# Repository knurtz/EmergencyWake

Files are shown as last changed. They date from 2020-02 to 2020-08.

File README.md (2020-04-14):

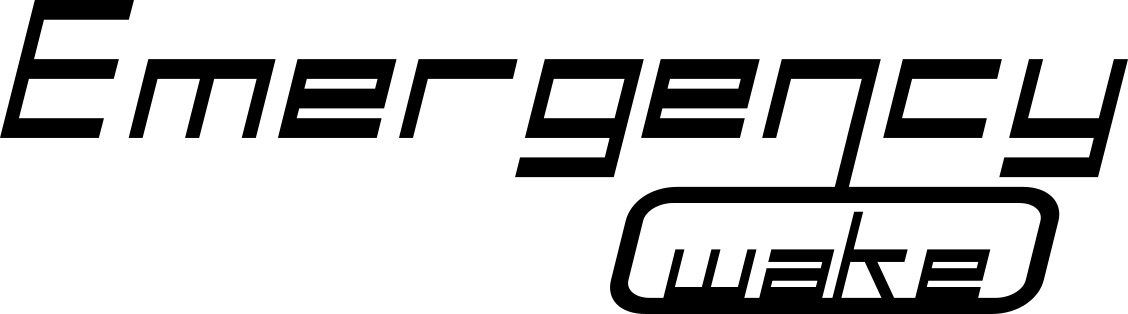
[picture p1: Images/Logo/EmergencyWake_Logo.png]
Emergency Wake


## Idea
A bedside alarm clock that uses a big red [emergency brake lever](https://www.google.com/search?tbm=isch&q=notbremse%20zug&tbs=imgo:1) as a snooze button.

To display the time, a vintage [VFD](https://en.wikipedia.org/wiki/Vacuum_fluorescent_display) is used.

An STM32 microcontroller and its RTC unit is used for tracking the time. It's in deep sleep most of the time.

Soundfiles from an SD card can be read by the microcontroller and played back through a small speaker.

Because of the VFD's relatively high power consumption, the clock can't run on battery power alone, so a USB-C connector is used for a 5 V power supply. 

In case of a power outage, a 3 V coin cell battery powers the microcontroller. In this scenario a small buzzer will be used instead of a wakeup melody, in order to use as little power as possible and to also notify the user, something's wrong. Also the display won't work.

Also, there will be support for a [DCF77](https://en.wikipedia.org/wiki/DCF77) radio clock module to automatically update the time.

A toggle switch allows programming two independent alarms. The times are set using a rotary encoder.

## Resources
- [Useful information](http://www.vwlowen.co.uk/arduino/vfd/vfd-clock.htm) about VFDs
- [A Guide to Fundamental VFD Operation](https://www.noritake-elec.com/technology/general-technical-information/vfd-operation)
- [Instructables page](https://www.instructables.com/id/A-Simple-Driver-for-VFD-Displays/) about controlling VFDs
- [Github project](https://github.com/AndruPol/ChibiOS-WavePlayer) about an STM32 wave player with ChibiOS
- [Github project](https://github.com/vanbwodonk/F4D_MP3) about an STM32 MP3 decoder
- [Another Github project](https://github.com/no111u3/stm32f4d_encoder/blob/master/main.c) about using the timer's encoder mode

## Components
- used emergency brake from eBay
- VFD from [pollin.de](https://www.pollin.de/p/vakuum-fluoreszenzdisplay-futaba-4-lt-46zb3-4-digit-121537) with additional parts:
  - [PT6312B](https://datasheet.lcsc.com/szlcsc/Princeton-Tech-PT6312B_C110225.pdf) VFD controller IC (requires negative voltages)
  - Alternative: UDN6118 VFD driver IC from eBay with no need for negative voltage
  - L9110 H-bridge for VFD filament
  - GL5516 light dependent resistor from eBay
- STM32F407VET6 microcontroller
- SD card holder from [Würth](https://www.we-online.de/katalog/datasheet/693071020811.pdf)
- DCF77 module from [pollin.de](https://www.pollin.de/p/dcf-empfangsmodul-dcf1-810054)
- CR2032 coin cell holder
- small buzzer
- toggle switch from [pollin.de](https://www.pollin.de/p/kippschalter-kn3-c-103a-1-polig-on-off-on-420023)
- rotary encoder from [reichelt.de](https://www.reichelt.de/drehimpulsegeber-15-impulse-30-rastungen-vertikal-stec11b03-p73913.html?r=1)
- MC34063 DCDC converter
- 5 V to 3.3 V step down regulator from [Würth](https://www.we-online.de/katalog/datasheet/173950378.pdf)
- [WM8960](https://datasheet.lcsc.com/szlcsc/Wolfson-Microelectronics-PLC-WM8960CGEFL-RV_C18752.pdf) audio codec with integrated class-D amplifier

## Usage
The clock will be in deep sleep most of the time. The display can be activated for about 10 seconds by tugging the emergency brake shortly.

While the time is being displayed, flipping the toggle switch into one of its two "on" positions allows setting the alarm times. In this mode, the alarms can each be (de-)activated by pulling the emergency lever once. A deactivated alarm will be represented by \_\_:\_\_ on the display.

Setting the alarm time is done by pressing the rotary encoder's push button to set the hours and then pressing it again to set the minutes. Alarm times are stored inside an EEPROM IC to avoid loss of settings after a power outage.

Once one alarm rings, pulling the emergency lever shortly will put it into snooze mode, pulling longer will deactivate the alarm.

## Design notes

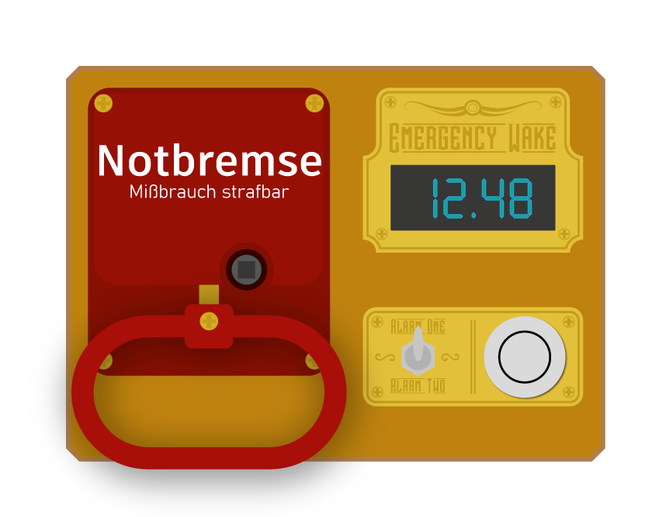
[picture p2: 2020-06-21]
BrassPlates/BrassPlateDisplay.png

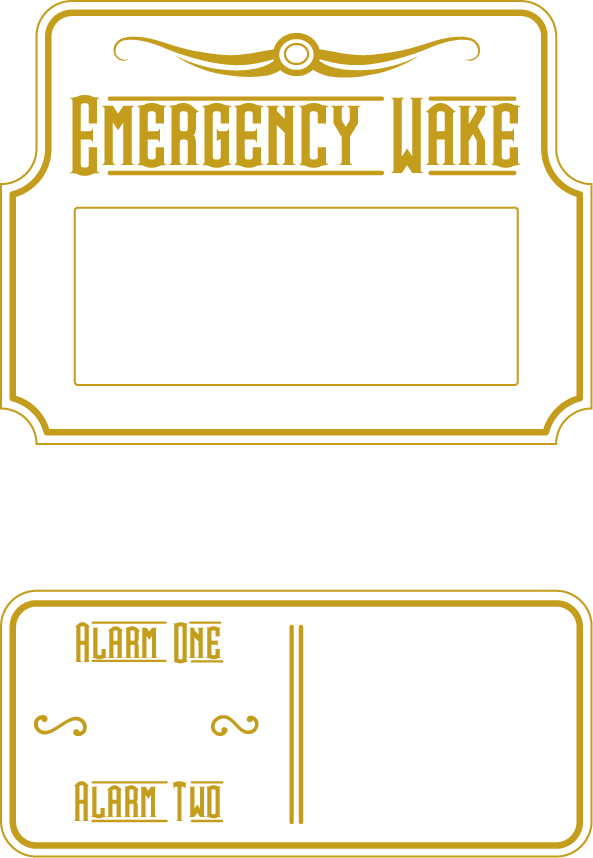
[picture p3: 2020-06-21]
BrassPlates/BrassPlateDisplay_PlaquesOnlyColor.png

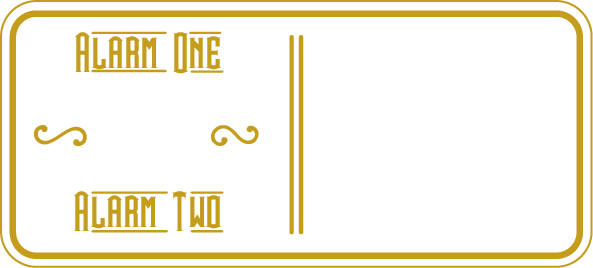
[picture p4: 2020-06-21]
BrassPlates/BrassPlateDisplay_LowerPlaqueOnly.png

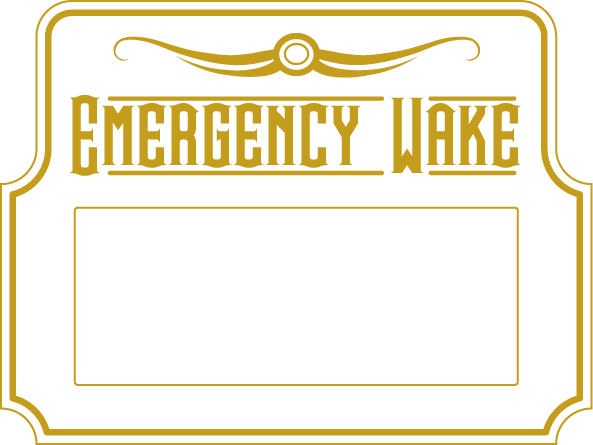
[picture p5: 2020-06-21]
BrassPlates/BrassPlateDisplay_UpperPlaqueOnly.png

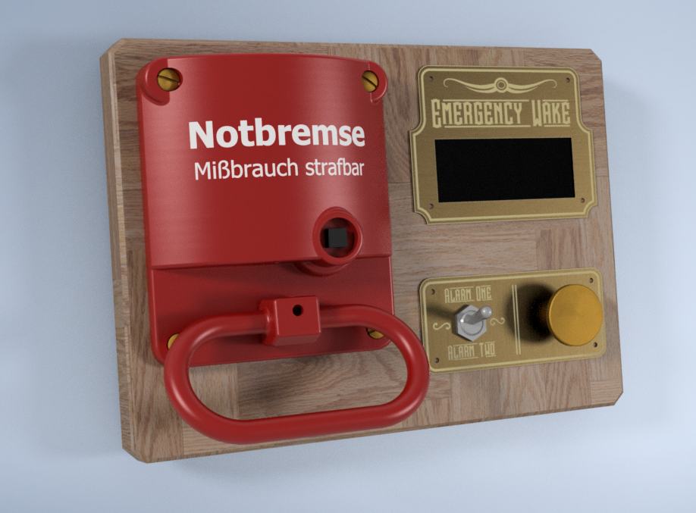
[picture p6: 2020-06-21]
CAD/Inventor/EmergencyWake.png

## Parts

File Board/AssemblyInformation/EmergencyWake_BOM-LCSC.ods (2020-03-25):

Designator | Comment | Footprint | LCSC Part #
C1 | 4u7,16V | Capacitor_SMD:C_0603_1608Metric | C19666
C8 C7 C6 C5 C4 C2 C23 C35 C15 C10 C39 C38 C37 | 100n | Capacitor_SMD:C_0402_1005Metric | C1525
C9 C26 C24 | 10u,25V | Capacitor_SMD:C_0805_2012Metric | C15850
C13 C36 | 22u,25V | Capacitor_SMD:C_0805_2012Metric | C45783
C16 | 470p | Capacitor_SMD:C_0603_1608Metric | C1620
C17 C12 C25 | 1u,50V | Capacitor_SMD:C_0603_1608Metric | C15849
C19 C20 | 30p | Capacitor_SMD:C_0402_1005Metric | C1570
C21 C22 | 15p | Capacitor_SMD:C_0402_1005Metric | C1548
C30 C31 C27 C29 C28 C32 C3 C11 | 10n,50V | Capacitor_SMD:C_0402_1005Metric | C15195
C34 C33 | 2.2u | Capacitor_SMD:C_0603_1608Metric | C23630
D2 D3 D4 D1 | white | LED_SMD:LED_0805_2012Metric_Castellated | C34499
D6 D5 | SS54 | Diode_SMD:D_SMA | C22452
Q1 Q3 | AO3400A | Package_TO_SOT_SMD:SOT-23 | C20917
Q2 Q4 Q5 | AO3401A | Package_TO_SOT_SMD:SOT-23 | C15127
R3 R2 R4 R5 | 150 | Resistor_SMD:R_0402_1005Metric | C25082
R9 R11 R31 R32 R33 R28 R29 R34 R8 R1 R10 R12 R13 R14 R16 R40 R15 R17 R47 R48 R30 R49 R50 R42 | 100k | Resistor_SMD:R_0402_1005Metric | C25741
R19 | 75k | Resistor_SMD:R_0603_1608Metric | C23242
R20 R6 R43 | 5.1k | Resistor_SMD:R_0603_1608Metric | C23186
R23 | 20k | Resistor_SMD:R_0603_1608Metric | C4184
R25 | 51k | Resistor_SMD:R_0603_1608Metric | C23196
R26 R27 R7 R44 R45 R46 | 10k | Resistor_SMD:R_0402_1005Metric | C25744
R35 R36 | 390 | Resistor_SMD:R_0603_1608Metric | C23151
R39 R38 R37 | 10k | Resistor_SMD:R_0603_1608Metric | C25804
U1 | M24C02-WMN | Package_SO:SOIC-8_3.9x4.9mm_P1.27mm | C7562
U2 | AMS1117-3.3 | Package_TO_SOT_SMD:SOT-223-3_TabPin2 | C6186
U3 | MC34063AD | Package_SO:SOIC-8_3.9x4.9mm_P1.27mm | C32078
U4 | STM32F407VETx | Package_QFP:LQFP-100_14x14mm_P0.5mm | C28730
U7 | PT6312B | Package_QFP:LQFP-44_10x10mm_P0.8mm | C110225
U9 U8 | EL357N-G | Package_SO:SOP-4_3.8x4.1mm_P2.54mm | C6649
U10 | L9110S | Package_SO:SOP-8_3.76x4.96mm_P1.27mm | C85174
U11 | SRV05-4 | Package_TO_SOT_SMD:SOT-23-6 | C85364
Y1 | 32768 | Crystal:Crystal_SMD_3215-2Pin_3.2x1.5mm | C32346
Y2 | 8M | Crystal:Crystal_SMD_5032-2Pin_5.0x3.2mm | C115962

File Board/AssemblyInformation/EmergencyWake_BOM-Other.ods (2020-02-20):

Reference | Quantity | Value | Footprint
BZ1 | 1 | Buzzer | Buzzer_Beeper:Buzzer_12x9.5RM7.6
DISP1 | 1 | FUTABA_4-LT-46ZB3 | VFD:FUTABA_4-LT-46ZB3
J3 | 1 | Conn_01x03 | Connector_PinHeader_2.54mm:PinHeader_1x03_P2.54mm_Horizontal
J5 | 1 | Conn_01x05 | Connector_PinHeader_2.54mm:PinHeader_1x05_P2.54mm_Horizontal
J7,J4 | 2 | Conn_01x02 | Connector_PinHeader_2.54mm:PinHeader_1x02_P2.54mm_Horizontal
J8,J10 | 2 | Conn_01x04 | WR-WTB:WR-WTB 2.00mm SMT Male Horizontal Shrouded Header 4 Pins
J9,J6 | 2 | Conn_01x04 | Connector_PinHeader_2.54mm:PinHeader_1x04_P2.54mm_Horizontal
JP4,JP1,JP2,JP3 | 4 | SolderJumper_3_Open | Jumper:SolderJumper-3_P1.3mm_Open_RoundedPad1.0x1.5mm_NumberLabels
JP5,JP6 | 2 | SolderJumper_2_Open | Jumper:SolderJumper-2_P1.3mm_Open_TrianglePad1.0x1.5mm
NT1 | 1 | Net-Tie_2 | NetTie:NetTie-2_SMD_Pad2.0mm
R24 | 1 | GL5516 | OptoDevice:R_LDR_5.1x4.3mm_P3.4mm_Vertical
TP1 | 1 | 5V in | TestPoint:TestPoint_Loop_D1.80mm_Drill1.0mm_Beaded
TP10 | 1 | Vdrive | TestPoint:TestPoint_Loop_D1.80mm_Drill1.0mm_Beaded
TP11 | 1 | DCF | TestPoint:TestPoint_Loop_D1.80mm_Drill1.0mm_Beaded
TP2 | 1 | GND in | TestPoint:TestPoint_Loop_D1.80mm_Drill1.0mm_Beaded
TP3 | 1 | 5V | TestPoint:TestPoint_Loop_D1.80mm_Drill1.0mm_Beaded
TP4 | 1 | VCC | TestPoint:TestPoint_Loop_D1.80mm_Drill1.0mm_Beaded
TP5 | 1 | DCDC in | TestPoint:TestPoint_Loop_D1.80mm_Drill1.0mm_Beaded
TP6 | 1 | GND | TestPoint:TestPoint_Loop_D1.80mm_Drill1.0mm_Beaded
TP7 | 1 | Audio | TestPoint:TestPoint_Loop_D1.80mm_Drill1.0mm_Beaded
TP8 | 1 | -VDC | TestPoint:TestPoint_Loop_D1.80mm_Drill1.0mm_Beaded
TP9 | 1 | LDR | TestPoint:TestPoint_Loop_D1.80mm_Drill1.0mm_Beaded

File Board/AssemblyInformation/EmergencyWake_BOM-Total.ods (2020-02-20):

Reference | Quantity | Value | Footprint | Würth | LCSC
C8,C7,C6,C5,C4,C2,C23,C35,C15,C10 | 10 | 100n | Capacitor_SMD:C_0402_1005Metric |  | C1525
C16 | 1 | 470p | Capacitor_SMD:C_0603_1608Metric |  | C1620
R23 | 1 | 20k | Resistor_SMD:R_0603_1608Metric |  | C4184
U2 | 1 | AMS1117-3.3 | Package_TO_SOT_SMD:SOT-223-3_TabPin2 |  | C6186
U9,U8 | 2 | EL357N-G | Package_SO:SOP-4_3.8x4.1mm_P2.54mm |  | C6649
U1 | 1 | M24C02-WMN | Package_SO:SOIC-8_3.9x4.9mm_P1.27mm |  | C7562
C9 | 1 | 10u,50V | Capacitor_SMD:C_1206_3216Metric |  | C13585
Q2 | 1 | AO3401A | Package_TO_SOT_SMD:SOT-23 |  | C15127
C30,C31,C27,C29,C28,C32,C3,C11 | 8 | 10n,50V | Capacitor_SMD:C_0402_1005Metric |  | C15195
C17,C12,C25,C24 | 4 | 1u,50V | Capacitor_SMD:C_0603_1608Metric |  | C15849
C26 | 1 | 10u,50V | Capacitor_SMD:C_0805_2012Metric |  | C15850
C1 | 1 | 4u7,16V | Capacitor_SMD:C_0603_1608Metric |  | C19666
Q1,Q3 | 2 | AO3400A | Package_TO_SOT_SMD:SOT-23 |  | C20917
D6,D5 | 2 | SS54 | Diode_SMD:D_SMA |  | C22452
R22,R21 | 2 | 300k | Resistor_SMD:R_0603_1608Metric |  | C23024
R35,R36 | 2 | 390 | Resistor_SMD:R_0603_1608Metric |  | C23151
R20,R6,R43 | 3 | 5.1k | Resistor_SMD:R_0603_1608Metric |  | C23186
R25 | 1 | 51k | Resistor_SMD:R_0603_1608Metric |  | C23196
R19 | 1 | 75k | Resistor_SMD:R_0603_1608Metric |  | C23242
C34,C33 | 2 | 2.2u | Capacitor_SMD:C_0603_1608Metric |  | C23630
R3,R2,R4,R5 | 4 | 150 | Resistor_SMD:R_0402_1005Metric |  | C25082
R9,R11,R31,R32,R33,R28,R30,R29,R34,R8,R1,R10,R12,R13,R14,R16,R40,R15,R17,R41,R42,R47,R48 | 23 | 100k | Resistor_SMD:R_0402_1005Metric |  | C25741
R26,R27,R7,R44,R45,R46 | 6 | 10k | Resistor_SMD:R_0402_1005Metric |  | C25744
R39,R38,R37 | 3 | 10k | Resistor_SMD:R_0603_1608Metric |  | C25804
U4 | 1 | STM32F407VETx | Package_QFP:LQFP-100_14x14mm_P0.5mm |  | C28730
U3 | 1 | MC34063AD | Package_SO:SOIC-8_3.9x4.9mm_P1.27mm |  | C32078
D2,D3,D4,D1 | 4 | white | LED_SMD:LED_0805_2012Metric_Castellated |  | C34499
C21,C22 | 2 | 6p | Capacitor_SMD:C_0402_1005Metric |  | C37474
C13 | 1 | 22u,25V | Capacitor_SMD:C_0805_2012Metric |  | C45783
C19,C20 | 2 | 10n | Capacitor_SMD:C_0603_1608Metric |  | C57112
U10 | 1 | L9110S | Package_SO:SOP-8_3.76x4.96mm_P1.27mm |  | C85174
U11 | 1 | SRV05-4 | Package_TO_SOT_SMD:SOT-23-6 |  | C85364
Y1 | 1 | 32768 | Crystal:Crystal_SMD_3215-2Pin_3.2x1.5mm |  | C94673
U7, | 1 | PT6312B | Package_QFP:LQFP-44_10x10mm_P0.8mm |  | C110225
U5 | 1 | LM4670 | Package_SON:WSON-8-1EP_3x3mm_P0.5mm_EP1.6x2.0mm |  | C131968
BT1 | 1 | Battery_Cell | Wuerth:79523141 | 79523141
U6 | 1 | 173950378 | Converter_DCDC:Converter_DCDC_RECOM_R-78B-2.0_THT | 173950378
L1 | 1 | 33u | Inductor_SMD:L_Wuerth_WE-PD-Typ-7345 | 7447773330
SW4,SW3,SW2 | 3 | SW_Push | Wuerth:436351045816 | 436351045816
SW1 | 1 | SW_DPDT_x2 | Wuerth:452404020202 | 452404020202
R18 | 1 | 0.18 | Wuerth:561070332057 | 561070332057
J1 | 1 | USB_C_Receptacle_USB2.0 | Wuerth:632723300011 | 632723300011
J2 | 1 | Micro_SD_Card_Det | Wuerth:693071020811 | 693071020811
C14 | 1 | 100u,50V | Capacitor_THT:CP_Radial_D6.3mm_P2.50mm | 860010573007
C18 | 1 | 33u,63V | Capacitor_THT:CP_Radial_D6.3mm_P2.50mm | 860010773011
BZ1 | 1 | Buzzer | Buzzer_Beeper:Buzzer_12x9.5RM7.6
DISP1 | 1 | FUTABA_4-LT-46ZB3 | VFD:FUTABA_4-LT-46ZB3
J3 | 1 | Conn_01x03 | Connector_PinHeader_2.54mm:PinHeader_1x03_P2.54mm_Horizontal
J5 | 1 | Conn_01x05 | Connector_PinHeader_2.54mm:PinHeader_1x05_P2.54mm_Horizontal
J7,J4 | 2 | Conn_01x02 | Connector_PinHeader_2.54mm:PinHeader_1x02_P2.54mm_Horizontal
J8,J10 | 2 | Conn_01x04 | WR-WTB:WR-WTB 2.00mm SMT Male Horizontal Shrouded Header 4 Pins
J9,J6 | 2 | Conn_01x04 | Connector_PinHeader_2.54mm:PinHeader_1x04_P2.54mm_Horizontal
JP4,JP1,JP2,JP3 | 4 | SolderJumper_3_Open | Jumper:SolderJumper-3_P1.3mm_Open_RoundedPad1.0x1.5mm_NumberLabels
JP5,JP6 | 2 | SolderJumper_2_Open | Jumper:SolderJumper-2_P1.3mm_Open_TrianglePad1.0x1.5mm
NT1 | 1 | Net-Tie_2 | NetTie:NetTie-2_SMD_Pad2.0mm
R24 | 1 | GL5516 | OptoDevice:R_LDR_5.1x4.3mm_P3.4mm_Vertical
TP1 | 1 | 5V in | TestPoint:TestPoint_Loop_D1.80mm_Drill1.0mm_Beaded
TP10 | 1 | Vdrive | TestPoint:TestPoint_Loop_D1.80mm_Drill1.0mm_Beaded
TP11 | 1 | DCF | TestPoint:TestPoint_Loop_D1.80mm_Drill1.0mm_Beaded
TP2 | 1 | GND in | TestPoint:TestPoint_Loop_D1.80mm_Drill1.0mm_Beaded
TP3 | 1 | 5V | TestPoint:TestPoint_Loop_D1.80mm_Drill1.0mm_Beaded
TP4 | 1 | VCC | TestPoint:TestPoint_Loop_D1.80mm_Drill1.0mm_Beaded
TP5 | 1 | DCDC in | TestPoint:TestPoint_Loop_D1.80mm_Drill1.0mm_Beaded
TP6 | 1 | GND | TestPoint:TestPoint_Loop_D1.80mm_Drill1.0mm_Beaded
TP7 | 1 | Audio | TestPoint:TestPoint_Loop_D1.80mm_Drill1.0mm_Beaded
TP8 | 1 | -VDC | TestPoint:TestPoint_Loop_D1.80mm_Drill1.0mm_Beaded
TP9 | 1 | LDR | TestPoint:TestPoint_Loop_D1.80mm_Drill1.0mm_Beaded

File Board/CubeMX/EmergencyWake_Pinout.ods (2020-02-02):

Position | Name | Type | Signal | Label
94 | BOOT0 | Boot
73 | NC | NC
14 | NRST | Reset
12 | OSC_IN | I/O
13 | OSC_OUT | I/O
23 | PA0-WKUP | I/O | SYS_WKUP
24 | PA1 | I/O | GPIO_EXTI1 | Lever
25 | PA2 | I/O
26 | PA3 | Output | GPIO_Output | Audio EN
29 | PA4 | I/O | DAC_OUT1 | Audio out
30 | PA5 | I/O
31 | PA6 | I/O | ADC1_IN6 | LDR in
32 | PA7 | I/O
67 | PA8 | I/O
68 | PA9 | I/O | USART1_TX
69 | PA10 | I/O | USART1_RX
70 | PA11 | I/O | USB_DM
71 | PA12 | I/O | USB_DP
72 | PA13 | I/O | SYS_JTMS-SWDIO
76 | PA14 | I/O | SYS_JTCK-SWCLK
77 | PA15 | I/O | SPI1_NSS
35 | PB0 | I/O
36 | PB1 | Output | GPIO_Output | Buzzer
37 | PB2 | I/O
89 | PB3 | I/O | SPI1_SCK
90 | PB4 | I/O | SPI1_MISO
91 | PB5 | I/O | SPI1_MOSI
92 | PB6 | I/O | I2C1_SCL
93 | PB7 | I/O | I2C1_SDA
95 | PB8 | I/O
96 | PB9 | I/O
47 | PB10 | I/O
48 | PB11 | I/O
51 | PB12 | Output | GPIO_Output | SPI2_STB
52 | PB13 | I/O | SPI2_SCK
53 | PB14 | I/O | SPI2_MISO
54 | PB15 | I/O | SPI2_MOSI
15 | PC0 | Output | GPIO_Output | LED1
16 | PC1 | Output | GPIO_Output | LED2
17 | PC2 | Output | GPIO_Output | LED3
18 | PC3 | Output | GPIO_Output | LED4
33 | PC4 | I/O
34 | PC5 | I/O
63 | PC6 | I/O | TIM8_CH1
64 | PC7 | I/O | TIM8_CH2
65 | PC8 | I/O | SDIO_D0
66 | PC9 | I/O
78 | PC10 | I/O
79 | PC11 | I/O
80 | PC12 | I/O | SDIO_CK
7 | PC13-TAMPER-RTC | I/O
8 | PC14-OSC32_IN | I/O | RCC_OSC32_IN
9 | PC15-OSC32_OUT | I/O | RCC_OSC32_OUT
81 | PD0 | I/O
82 | PD1 | I/O
83 | PD2 | I/O | SDIO_CMD
84 | PD3 | I/O
85 | PD4 | I/O
86 | PD5 | Output | GPIO_Output | SD enable
87 | PD6 | Input | GPIO_Input | SD detect
88 | PD7 | I/O
55 | PD8 | I/O
56 | PD9 | I/O
57 | PD10 | I/O
58 | PD11 | I/O
59 | PD12 | I/O | TIM4_CH1
60 | PD13 | I/O | TIM4_CH2
61 | PD14 | I/O
62 | PD15 | Output | GPIO_Output | DCDC enable
97 | PE0 | Output | GPIO_Output | EEPROM_NWC
98 | PE1 | I/O
1 | PE2 | I/O | GPIO_EXTI2 | EncoderButton
2 | PE3 | I/O | GPIO_EXTI3 | ToggleUp
3 | PE4 | I/O | GPIO_EXTI4 | ToggleDown
4 | PE5 | I/O | GPIO_EXTI5 | USR_BUT
5 | PE6 | I/O
38 | PE7 | I/O
39 | PE8 | I/O
40 | PE9 | I/O | TIM1_CH1 | DCF77 signal
41 | PE10 | Output | GPIO_Output | DCF77 enable
42 | PE11 | I/O
43 | PE12 | I/O
44 | PE13 | I/O
45 | PE14 | I/O
46 | PE15 | Input | GPIO_Input | VBUS sense
6 | VBAT | Power
11 | VDD | Power
28 | VDD | Power
50 | VDD | Power
75 | VDD | Power
100 | VDD | Power
22 | VDDA | Power
20 | VREF- | Power
21 | VREF+ | Power
10 | VSS | Power
27 | VSS | Power
49 | VSS | Power
74 | VSS | Power
99 | VSS | Power
19 | VSSA | Power

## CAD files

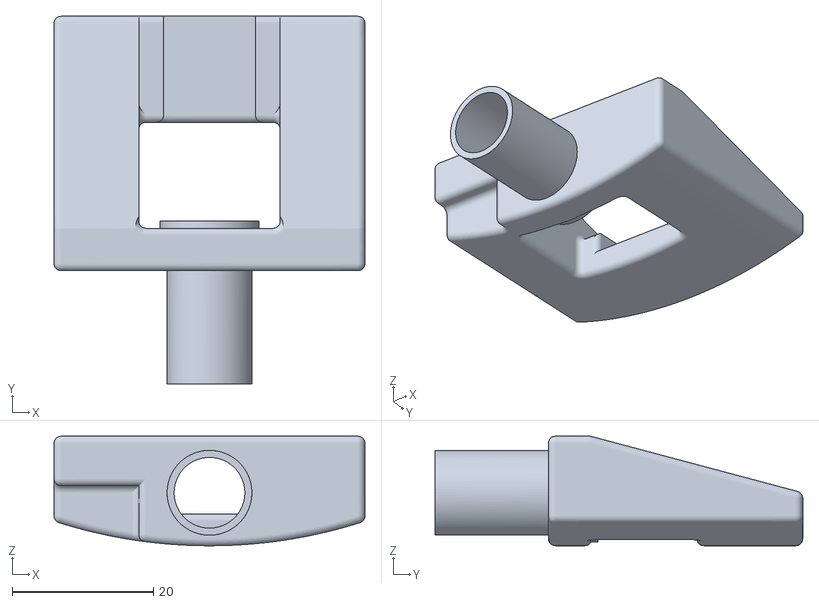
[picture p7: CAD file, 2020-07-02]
CAD/Inventor/STL/EW_KunststoffEinsatz.stl
44.0 x 52.0 x 15.5

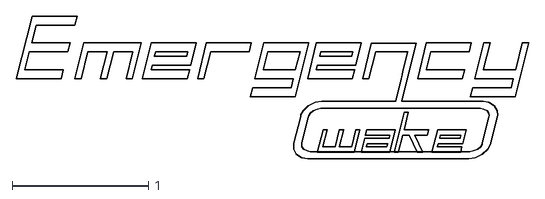
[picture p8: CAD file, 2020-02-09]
Images/Logo/EmergencyWake_Logo.dxf
3.76 x 1.05

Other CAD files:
CAD/Inventor/Board/436351045816_Download_STP_436351045816_rev1.iam
CAD/Inventor/Board/452404020202_Download_STP_452404020202_rev1.iam
CAD/Inventor/Board/632723300011_Download_STP_632723300011_rev1.iam
CAD/Inventor/Board/693071020811_Download_STEP_693071020811_rev1.iam
CAD/Inventor/Board/79523141_Download_STP_79523141_rev1.iam
CAD/Inventor/Board/Buzzer_12x9.5RM7.6.iam
CAD/Inventor/Board/COMPOUND.ipt
CAD/Inventor/Board/COMPOUND_1.ipt
CAD/Inventor/Board/COMPOUND_2.ipt
CAD/Inventor/Board/COMPOUND_3.ipt
CAD/Inventor/Board/COMPOUND_4.ipt
CAD/Inventor/Board/COMPOUND_5.ipt
CAD/Inventor/Board/COMPOUND_6.ipt
CAD/Inventor/Board/COMPOUND_7.ipt
CAD/Inventor/Board/CP_Radial_D6.3mm_P2.50mm.iam
CAD/Inventor/Board/C_0402_1005Metric.iam
CAD/Inventor/Board/C_0603_1608Metric.iam
CAD/Inventor/Board/C_0805_2012Metric.iam
CAD/Inventor/Board/Converter_DCDC_RECOM_R-78B-2.0_THT.iam
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

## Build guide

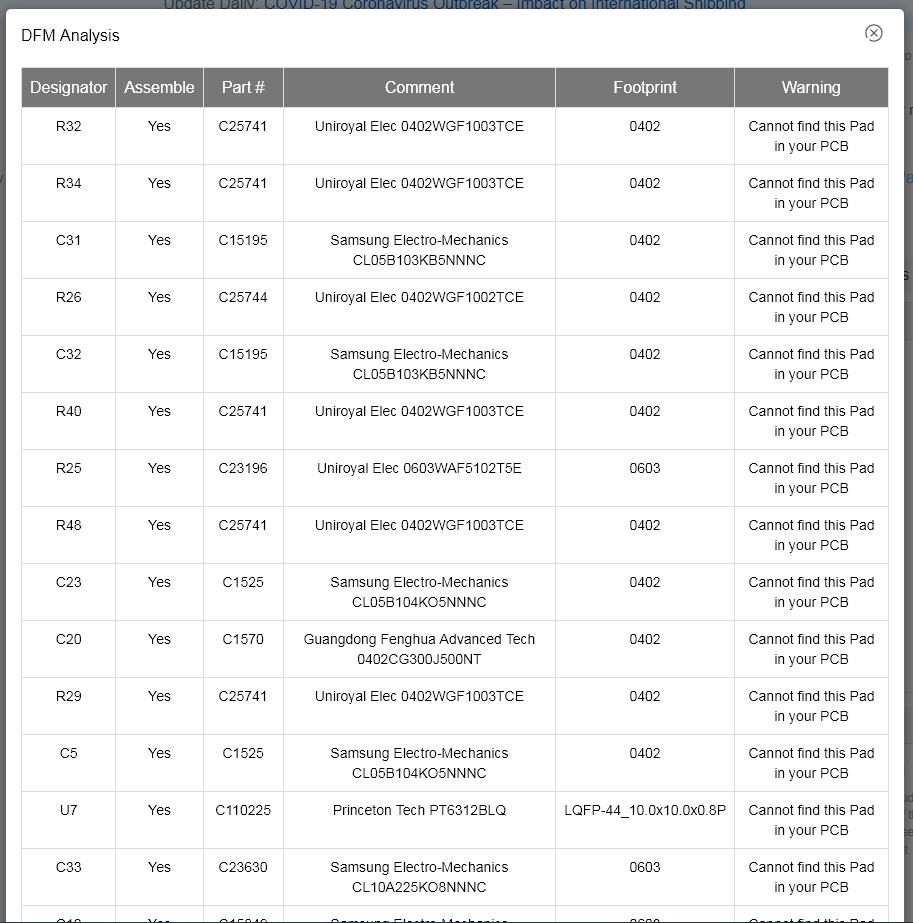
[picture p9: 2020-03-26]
Board/AssemblyInformation/DFM Analysis/00_DFM_Analysis01.png

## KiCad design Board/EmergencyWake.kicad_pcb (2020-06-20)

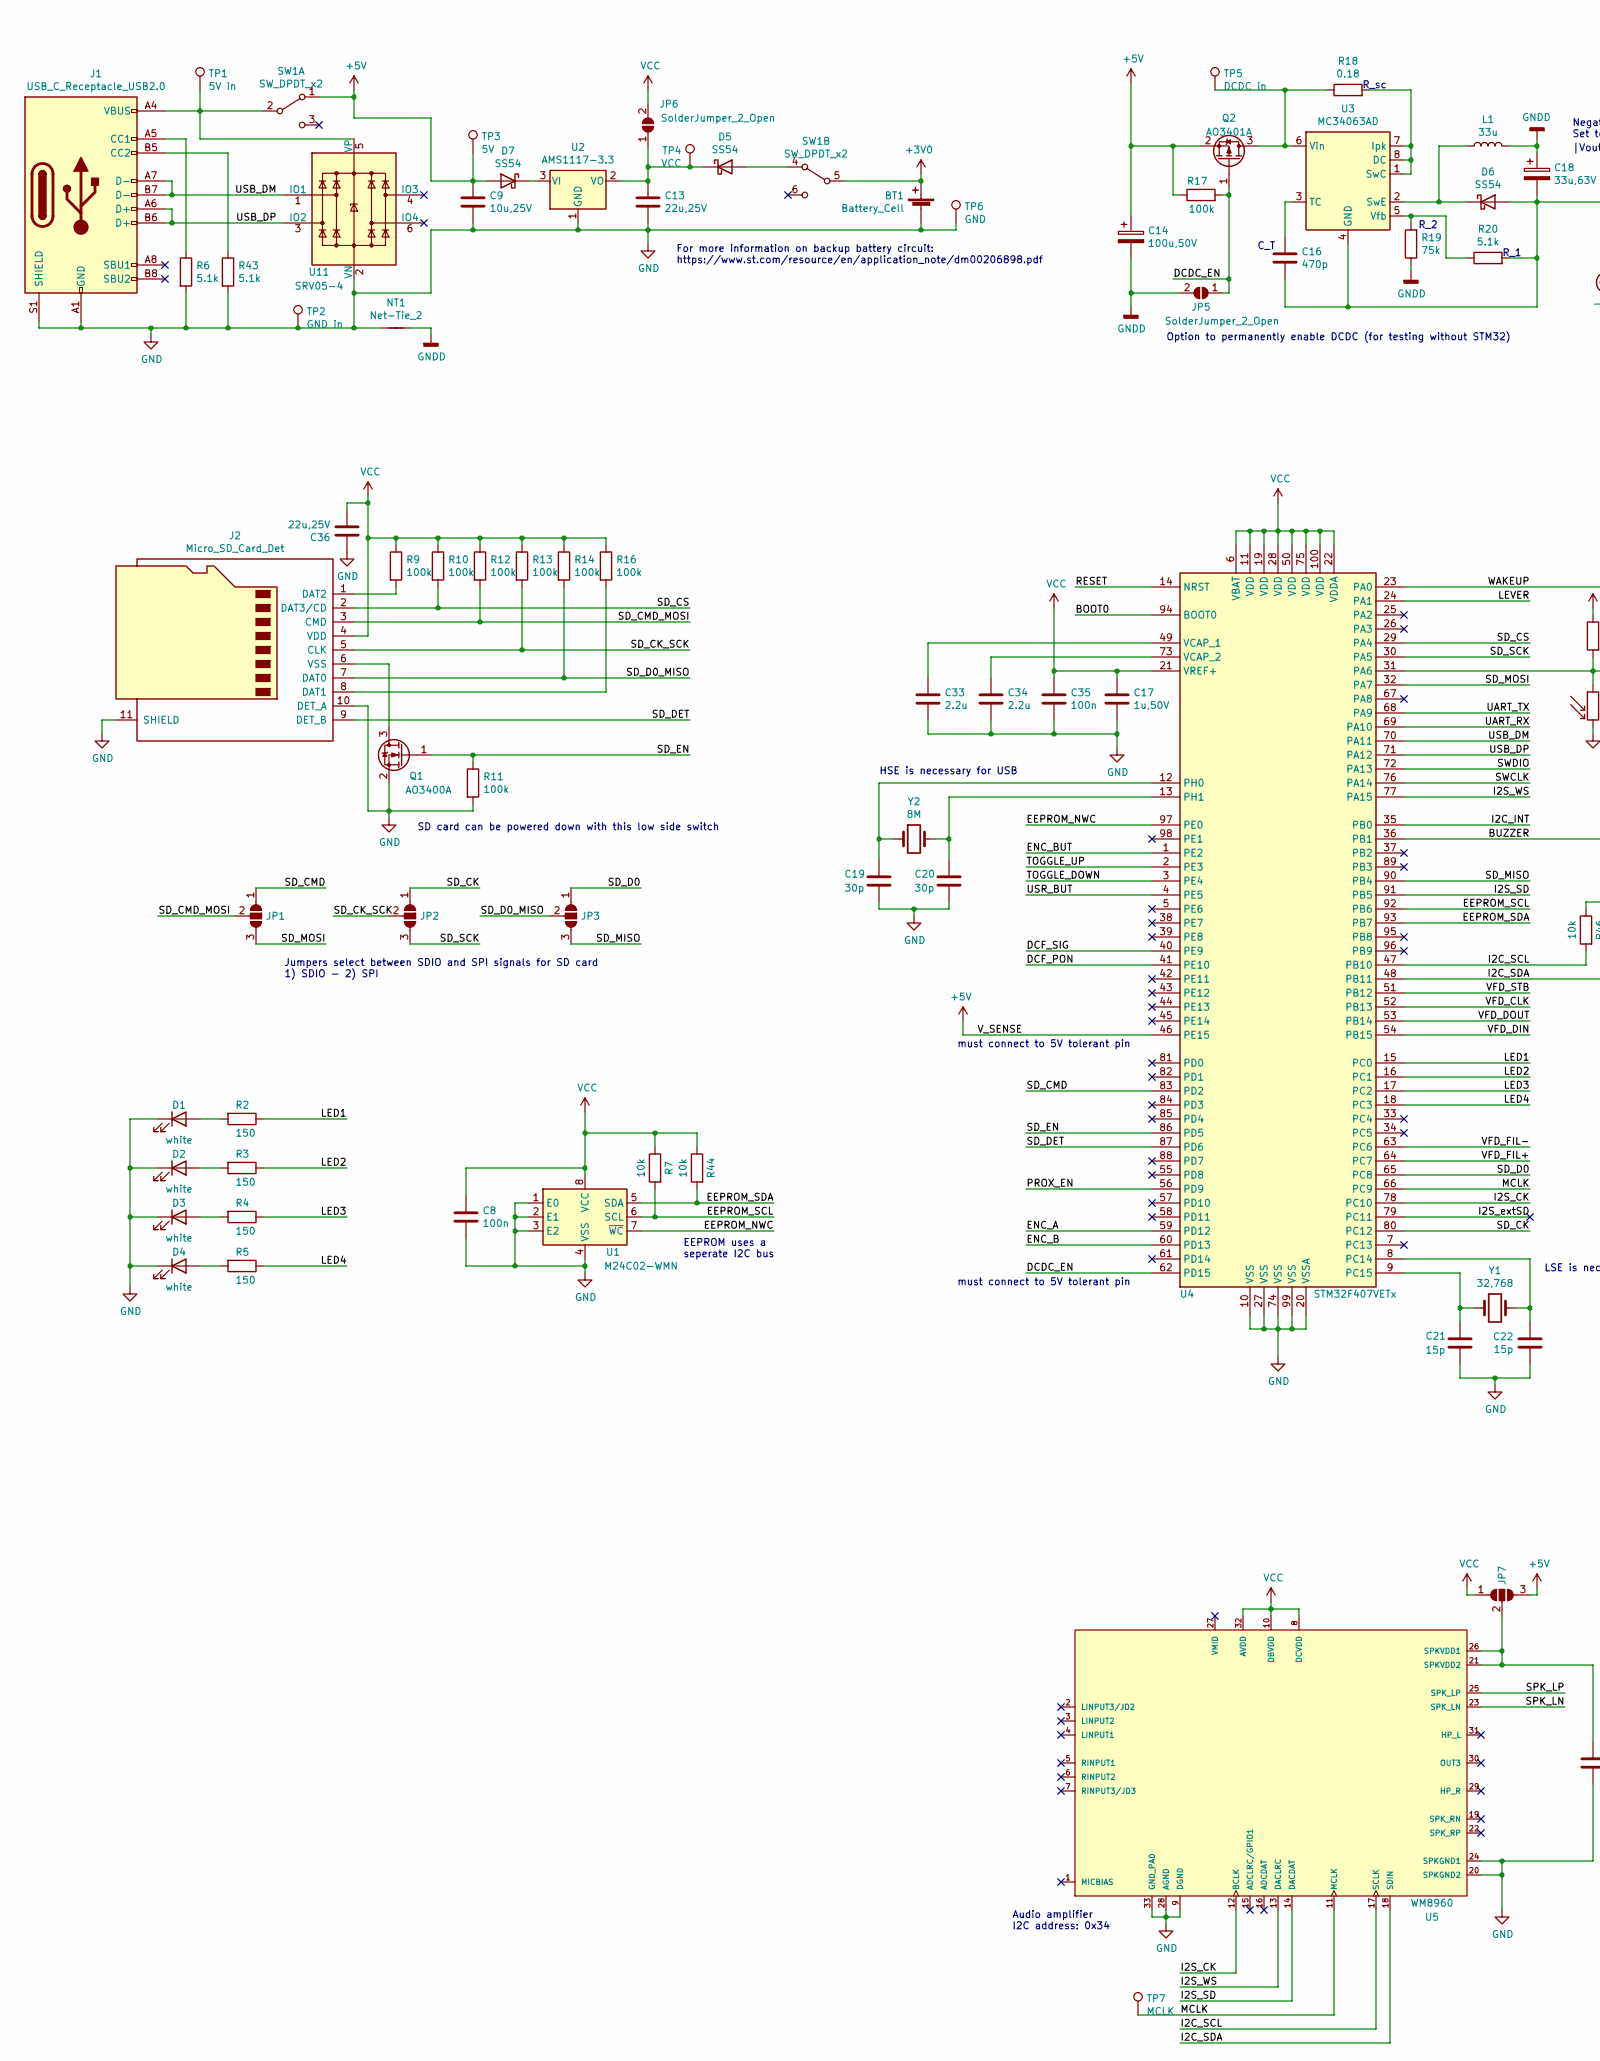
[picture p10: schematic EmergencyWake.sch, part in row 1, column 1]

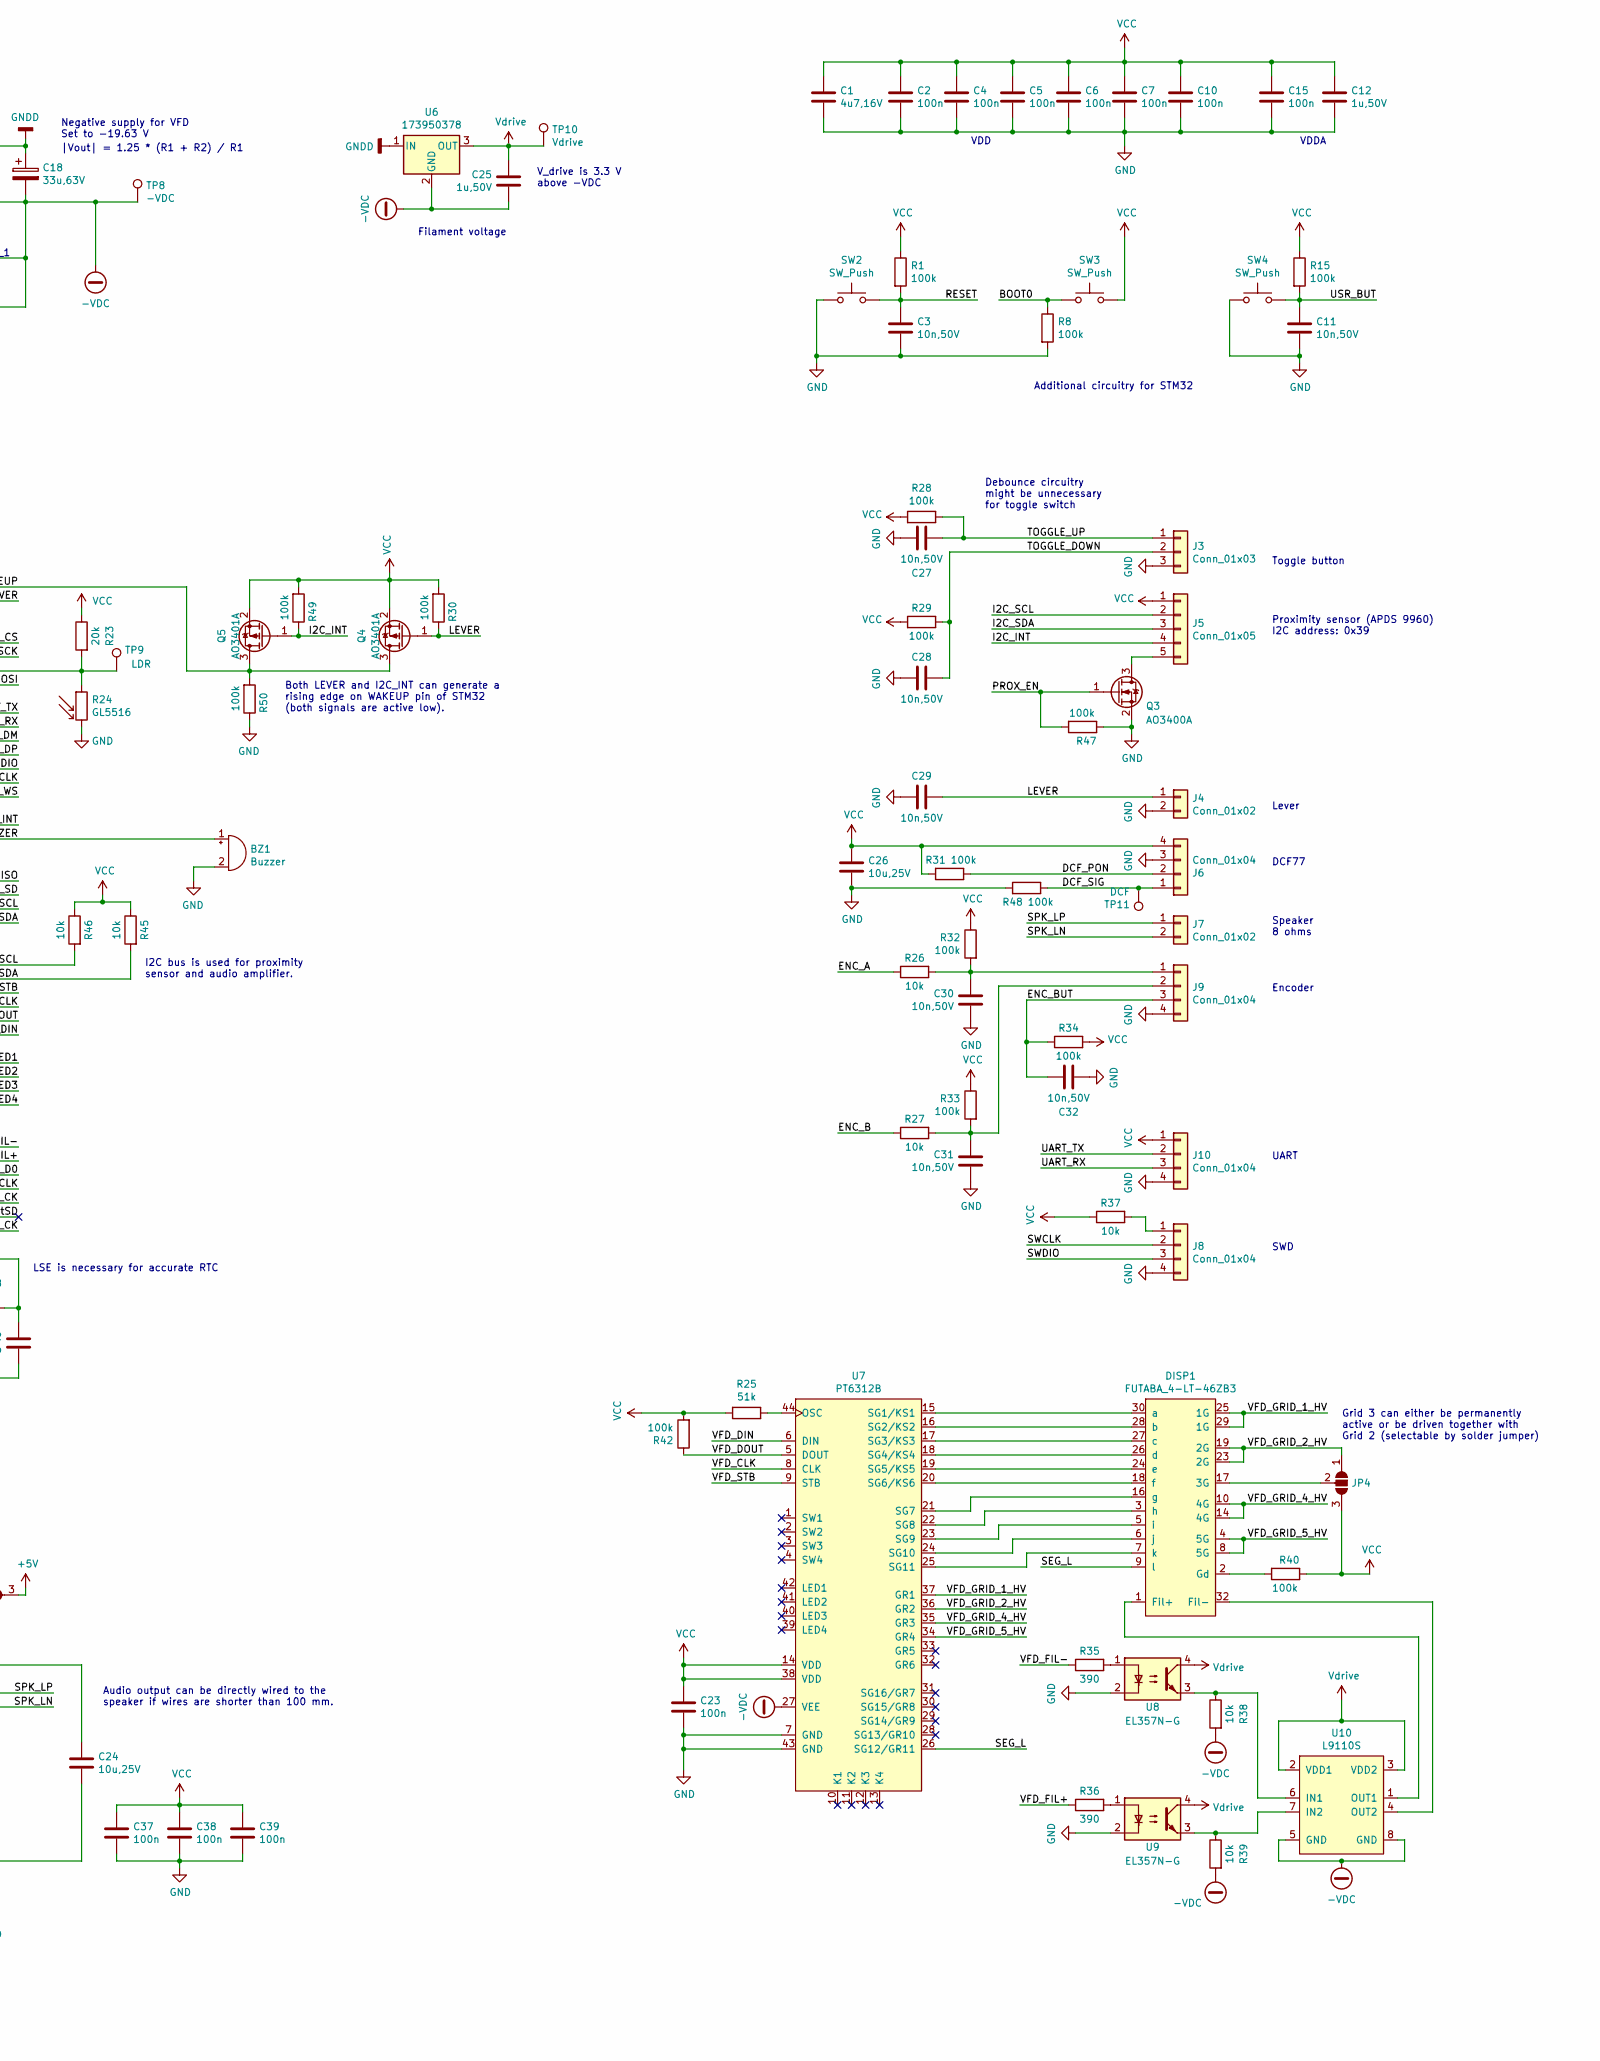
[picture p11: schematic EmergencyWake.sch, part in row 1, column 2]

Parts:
BT1: Battery_Cell; 79523141
BZ1: Buzzer; Buzzer_12x9.5RM7.6
C1: 4u7,16V; C_0603_1608Metric; LCSC C19666
C2, C4, C5, C6, C7, C8, C10, C15, C23, C35, C37, C38, C39: 100n; C_0402_1005Metric; LCSC C1525
C3, C11, C27, C28, C29, C30, C31, C32: 10n,50V; C_0402_1005Metric; LCSC C15195
C9, C24, C26: 10u,25V; C_0805_2012Metric; LCSC C15850
C12, C17, C25: 1u,50V; C_0603_1608Metric; LCSC C15849
C13, C36: 22u,25V; C_0805_2012Metric; LCSC C45783
C14: 100u,50V; CP_Radial_D6.3mm_P2.50mm
C16: 470p; C_0603_1608Metric; LCSC C1620
C18: 33u,63V; CP_Radial_D6.3mm_P2.50mm
C19, C20: 30p; C_0402_1005Metric; LCSC C1570
C21, C22: 15p; C_0402_1005Metric; LCSC C1548
C33, C34: 2.2u; C_0603_1608Metric; LCSC C23630
D1, D2, D3, D4: white; LED_0805_2012Metric_Castellated; LCSC C34499
D5, D6, D7: SS54; D_SMA; LCSC C22452
DISP1: FUTABA_4-LT-46ZB3
J1: USB_C_Receptacle_USB2.0; 632723300011
J2: Micro_SD_Card_Det; 693071020811
J3: Conn_01x03; PinHeader_1x03_P2.54mm_Horizontal
J4, J7: Conn_01x02; PinHeader_1x02_P2.54mm_Horizontal
J5: Conn_01x05; PinHeader_1x05_P2.54mm_Horizontal
J6, J9: Conn_01x04; PinHeader_1x04_P2.54mm_Horizontal
J8, J10: Conn_01x04; WR-WTB 2.00mm SMT Male Horizontal Shrouded Header 4 Pins
JP1, JP2, JP3, JP4, JP7: SolderJumper_3_Open; SolderJumper-3_P1.3mm_Open_RoundedPad1.0x1.5mm_NumberLabels
JP5, JP6: SolderJumper_2_Open; SolderJumper-2_P1.3mm_Open_TrianglePad1.0x1.5mm
L1: 33u; L_Wuerth_WE-PD-Typ-7345
NT1: Net-Tie_2; NetTie-2_SMD_Pad2.0mm
Q1, Q3: AO3400A; SOT-23; LCSC C20917
Q2, Q4, Q5: AO3401A; SOT-23; LCSC C15127
R1, R8, R9, R10, R11, R12, R13, R14, R15, R16, R17, R28, R29, R30, R31, R32, R33, R34, R40, R42, R47, R48, R49, R50: 100k; R_0402_1005Metric; LCSC C25741
R2, R3, R4, R5: 150; R_0402_1005Metric; LCSC C25082
R6, R20, R43: 5.1k; R_0603_1608Metric; LCSC C23186
R7, R44, R45, R46: 10k; R_0402_1005Metric; LCSC C25804
R18: 0.18; 561070332057
R19: 75k; R_0603_1608Metric; LCSC C23242
R23: 20k; R_0603_1608Metric; LCSC C4184
R24: GL5516; R_LDR_5.1x4.3mm_P3.4mm_Vertical
R25: 51k; R_0603_1608Metric; LCSC C23196
R26, R27: 10k; R_0402_1005Metric; LCSC C25744
R35, R36: 390; R_0603_1608Metric; LCSC C23151
R37, R38, R39: 10k; R_0603_1608Metric; LCSC C25804
SW1: SW_DPDT_x2; 452404020202
SW2, SW3, SW4: SW_Push; 436351045816
TP1: 5V in; TestPoint_Loop_D1.80mm_Drill1.0mm_Beaded
TP2: GND in; TestPoint_Loop_D1.80mm_Drill1.0mm_Beaded
TP3: 5V; TestPoint_Loop_D1.80mm_Drill1.0mm_Beaded
TP4: VCC; TestPoint_Loop_D1.80mm_Drill1.0mm_Beaded
TP5: DCDC in; TestPoint_Loop_D1.80mm_Drill1.0mm_Beaded
TP6: GND; TestPoint_Loop_D1.80mm_Drill1.0mm_Beaded
TP7: MCLK; TestPoint_Loop_D1.80mm_Drill1.0mm_Beaded
TP8: -VDC; TestPoint_Loop_D1.80mm_Drill1.0mm_Beaded
TP9: LDR; TestPoint_Loop_D1.80mm_Drill1.0mm_Beaded
TP10: Vdrive; TestPoint_Loop_D1.80mm_Drill1.0mm_Beaded
TP11: DCF; TestPoint_Loop_D1.80mm_Drill1.0mm_Beaded
U1: M24C02-WMN; SOIC-8_3.9x4.9mm_P1.27mm; LCSC C7562
U2: AMS1117-3.3; SOT-223-3_TabPin2; LCSC C6186
U3: MC34063AD; SOIC-8_3.9x4.9mm_P1.27mm; LCSC C32078
U4: STM32F407VETx; LQFP-100_14x14mm_P0.5mm; LCSC C28730
U5: WM8960; QFN-32-1EP_5x5mm_P0.5mm_EP3.45x3.45mm; LCSC C18752
U6: 173950378; Converter_DCDC_RECOM_R-78B-2.0_THT
U7: PT6312B; LQFP-44_10x10mm_P0.8mm; LCSC C110225
U8, U9: EL357N-G; SOP-4_3.8x4.1mm_P2.54mm; LCSC C6649
U10: L9110S; SOP-8_3.76x4.96mm_P1.27mm; LCSC C85174
U11: SRV05-4; SOT-23-6; LCSC C85364
Y1: 32,768; Crystal_SMD_3215-2Pin_3.2x1.5mm; LCSC C32346
Y2: 8M; Crystal_SMD_5032-2Pin_5.0x3.2mm; LCSC C115962

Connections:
+3V0: BT1.1 (+), SW1.5 (B)
+5V: C9.1, C14.1, D7.2 (A), JP7.3 (B), Q2.2 (S), R17.1, SW1.1 (A), TP3.1, U4.46 (PE15)
-VDC: C16.2, C18.2, C25.2, D6.2 (A), R20.2, R38.2, R39.2, TP8.1, U3.4 (GND), U6.2 (GND), U7.27 (VEE), U10.5 (GND), U10.8 (GND)
/BOOT0: R8.1, SW3.1, U4.94 (BOOT0)
/BUZZER: BZ1.1 (-), U4.36 (PB1)
/DCDC_EN: JP5.1 (A), Q2.1 (G), R17.2, U4.62 (PD15)
/DCF_PON: J6.2, R31.1, U4.41 (PE10)
/DCF_SIG: J6.1, R48.1, TP11.1, U4.40 (PE9)
/EEPROM_NWC: U1.7 (~WC), U4.97 (PE0)
/EEPROM_SCL: R7.2, U1.6 (SCL), U4.92 (PB6)
/EEPROM_SDA: R44.2, U1.5 (SDA), U4.93 (PB7)
/ENC_A: R26.1, U4.59 (PD12)
/ENC_B: R27.1, U4.60 (PD13)
/ENC_BUT: C32.2, J9.3, R34.1, U4.1 (PE2)
/I2C_INT: J5.4, Q5.1 (G), R49.1, U4.35 (PB0)
/I2C_SCL: J5.2, R46.2, U4.47 (PB10), U5.17 (SCLK)
/I2C_SDA: J5.3, R45.2, U4.48 (PB11), U5.18 (SDIN)
/I2S_CK: U4.78 (PC10), U5.12 (BCLK)
/I2S_SD: U4.91 (PB5), U5.14 (DACDAT)
/I2S_WS: U4.77 (PA15), U5.13 (DACLRC)
/I2S_extSD: U4.79 (PC11)
/LED1: R2.1, U4.15 (PC0)
/LED2: R3.1, U4.16 (PC1)
/LED3: R4.1, U4.17 (PC2)
/LED4: R5.1, U4.18 (PC3)
/LEVER: C29.2, J4.1, Q4.1 (G), R30.1, U4.24 (PA1)
/MCLK: TP7.1, U4.66 (PC9), U5.11 (MCLK)
/PROX_EN: Q3.1 (G), R47.2, U4.56 (PD9)
/RESET: C3.1, R1.2, SW2.2, U4.14 (NRST)
/SD_CK: JP2.1 (A), U4.80 (PC12)
/SD_CK_SCK: J2.5 (CLK), JP2.2 (C), R13.2
/SD_CMD: JP1.1 (A), U4.83 (PD2)
/SD_CMD_MOSI: J2.3 (CMD), JP1.2 (C), R12.2
/SD_CS: J2.2 (DAT3/CD), R10.2, U4.29 (PA4)
/SD_D0: JP3.1 (A), U4.65 (PC8)
/SD_D0_MISO: J2.7 (DAT0), JP3.2 (C), R14.2
/SD_DET: J2.9 (DET_B), U4.87 (PD6)
/SD_EN: Q1.1 (G), R11.1, U4.86 (PD5)
/SD_MISO: JP3.3 (B), U4.90 (PB4)
/SD_MOSI: JP1.3 (B), U4.32 (PA7)
/SD_SCK: JP2.3 (B), U4.30 (PA5)
/SEG_L: DISP1.9 (l), U7.26 (SG12/GR11)
/SPK_LN: J7.2, U5.23 (SPK_LN)
/SPK_LP: J7.1, U5.25 (SPK_LP)
/SWCLK: J8.2, U4.76 (PA14)
/SWDIO: J8.3, U4.72 (PA13)
/TOGGLE_DOWN: C28.2, J3.2, R29.1, U4.3 (PE4)
/TOGGLE_UP: C27.2, J3.1, R28.1, U4.2 (PE3)
/UART_RX: J10.3, U4.69 (PA10)
/UART_TX: J10.2, U4.68 (PA9)
/USB_DM: J1.A7 (D-), J1.B7 (D-), U4.70 (PA11), U11.1 (IO1)
/USB_DP: J1.A6 (D+), J1.B6 (D+), U4.71 (PA12), U11.3 (IO2)
/USR_BUT: C11.1, R15.2, SW4.2, U4.4 (PE5)
/VFD_CLK: U4.52 (PB13), U7.8 (CLK)
/VFD_DIN: U4.54 (PB15), U7.6 (DIN)
/VFD_DOUT: R42.1, U4.53 (PB14), U7.5 (DOUT)
/VFD_FIL+: R36.1, U4.64 (PC7)
/VFD_FIL-: R35.1, U4.63 (PC6)
/VFD_GRID_1_HV: DISP1.25 (1G), DISP1.29 (1G), U7.37 (GR1)
/VFD_GRID_2_HV: DISP1.19 (2G), DISP1.23 (2G), JP4.1 (A), U7.36 (GR2)
/VFD_GRID_4_HV: DISP1.10 (4G), DISP1.14 (4G), U7.35 (GR3)
/VFD_GRID_5_HV: DISP1.4 (5G), DISP1.8 (5G), U7.34 (GR4)
/VFD_STB: U4.51 (PB12), U7.9 (STB)
/WAKEUP: Q4.3 (D), Q5.3 (D), R50.2, U4.23 (PA0)
GND: BT1.2 (-), BZ1.2 (+), C1.2, C2.2, C3.2, C4.2, C5.2, C6.2, C7.2, C8.2, C9.2, C10.2, C11.2, C12.2, C13.2, C15.2, C17.2, C19.2, C20.2, C21.2, C22.2, C23.2, C24.2, C26.2, C27.1, C28.1, C29.1, C30.2, C31.2, C32.1, C33.2, C34.2, C35.2, C36.1, C37.2, C38.2, C39.2, D1.1 (K), D2.1 (K), D3.1 (K), D4.1 (K), J1.A1 (GND), J1.A12 (GND), J1.B1 (GND), J1.B12 (GND), J1.S1 (SHIELD), J2.10 (DET_A), J2.11 (SHIELD), J3.3, J4.2, J6.3, J8.4, J9.4, J10.4, NT1.1, Q1.2 (S), Q3.2 (S), R6.2, R8.2, R11.2, R24.2, R43.2, R47.1, R48.2, R50.1, SW2.1, SW4.1, TP2.1, TP6.1, U1.1 (E0), U1.2 (E1), U1.3 (E2), U1.4 (VSS), U2.1 (GND), U4.10 (VSS), U4.20 (VSSA), U4.27 (VSS), U4.74 (VSS), U4.99 (VSS), U5.9 (DGND), U5.20 (SPKGND2), U5.24 (SPKGND1), U5.28 (AGND), U5.33 (GND_PAD), U7.7 (GND), U7.43 (GND), U8.2, U9.2, U11.2 (VN)
GNDD: C14.2, C18.1, JP5.2 (B), L1.2, NT1.2, R19.1, U6.1 (IN)
unnamed: C13.1, D5.1 (K), JP6.1 (A), TP4.1, U2.2 (VO)
unnamed: C16.1, U3.3 (TC)
unnamed: C19.1, U4.12 (PH0), Y2.1
unnamed: C20.1, U4.13 (PH1), Y2.2
unnamed: C21.1, U4.9 (PC15), Y1.1
unnamed: C22.1, U4.8 (PC14), Y1.2
unnamed: C24.1, JP7.2 (C), U5.21 (SPKVDD2), U5.26 (SPKVDD1)
unnamed: C30.1, J9.1, R26.2, R32.2
unnamed: C31.1, J9.2, R27.2, R33.2
unnamed: C33.1, U4.49 (VCAP_1)
unnamed: C34.1, U4.73 (VCAP_2)
unnamed: D1.2 (A), R2.2
unnamed: D2.2 (A), R3.2
unnamed: D3.2 (A), R4.2
unnamed: D4.2 (A), R5.2
unnamed: D5.2 (A), SW1.4 (A)
unnamed: D6.1 (K), L1.1, U3.2 (SwE)
unnamed: D7.1 (K), U2.3 (VI)
unnamed: DISP1.1 (Fil+), U10.1 (OUT1)
unnamed: DISP1.2 (Gd), R40.2
unnamed: DISP1.3 (h), U7.22 (SG8)
unnamed: DISP1.5 (i), U7.23 (SG9)
unnamed: DISP1.6 (j), U7.24 (SG10)
unnamed: DISP1.7 (k), U7.25 (SG11)
unnamed: DISP1.16 (g), U7.21 (SG7)
unnamed: DISP1.17 (3G), JP4.2 (C)
unnamed: DISP1.18 (f), U7.20 (SG6/KS6)
unnamed: DISP1.24 (e), U7.19 (SG5/KS5)
unnamed: DISP1.26 (d), U7.18 (SG4/KS4)
unnamed: DISP1.27 (c), U7.17 (SG3/KS3)
unnamed: DISP1.28 (b), U7.16 (SG2/KS2)
unnamed: DISP1.30 (a), U7.15 (SG1/KS1)
unnamed: DISP1.32 (Fil-), U10.4 (OUT2)
unnamed: J1.A4 (VBUS), J1.A9 (VBUS), J1.B4 (VBUS), J1.B9 (VBUS), SW1.2 (B), TP1.1, U11.5 (VP)
unnamed: J1.A5 (CC1), R6.1
unnamed: J1.B5 (CC2), R43.1
unnamed: J2.1 (DAT2), R9.2
unnamed: J2.6 (VSS), Q1.3 (D)
unnamed: J2.8 (DAT1), R16.2
unnamed: J5.5, Q3.3 (D)
unnamed: J8.1, R37.2
unnamed: Q2.3 (D), R18.1, TP5.1, U3.6 (Vin)
unnamed: R18.2, U3.1 (SwC), U3.7 (Ipk), U3.8 (DC)
unnamed: R19.2, R20.1, U3.5 (Vfb)
unnamed: R23.2, R24.1, TP9.1, U4.31 (PA6)
unnamed: R25.1, U7.44 (OSC)
unnamed: R35.2, U8.1
unnamed: R36.2, U9.1
unnamed: R38.1, U8.3, U10.6 (IN1)
unnamed: R39.1, U9.3, U10.7 (IN2)
VCC: C1.1, C2.1, C4.1, C5.1, C6.1, C7.1, C8.1, C10.1, C12.1, C15.1, C17.1, C23.1, C26.1, C35.1, C36.2, C37.1, C38.1, C39.1, J2.4 (VDD), J5.1, J6.4, J10.1, JP4.3 (B), JP6.2 (B), JP7.1 (A), Q4.2 (S), Q5.2 (S), R1.1, R7.1, R9.1, R10.1, R12.1, R13.1, R14.1, R15.1, R16.1, R23.1, R25.2, R28.2, R29.2, R30.2, R31.2, R32.1, R33.1, R34.2, R37.1, R40.1, R42.2, R44.1, R45.1, R46.1, R49.2, SW3.2, U1.8 (VCC), U4.6 (VBAT), U4.11 (VDD), U4.19 (VDD), U4.21 (VREF+), U4.22 (VDDA), U4.28 (VDD), U4.50 (VDD), U4.75 (VDD), U4.100 (VDD), U5.8 (DCVDD), U5.10 (DBVDD), U5.32 (AVDD), U7.14 (VDD), U7.38 (VDD)
Vdrive: C25.1, TP10.1, U6.3 (OUT), U8.4, U9.4, U10.2 (VDD1), U10.3 (VDD2)

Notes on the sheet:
SWD
Speaker 8 ohms
DCF77
Toggle button
Lever
Encoder
must connect to 5V tolerant pin
For more information on backup battery circuit: https://www.st.com/resource/en/application_note/dm00206898.pdf
Debounce circuitry might be unnecessary for toggle switch
Grid 3 can either be permanently active or be driven together with Grid 2 (selectable by solder jumper)
Negative supply for VFD Set to -19.63 V
R_1
C_T
R_sc
|Vout| = 1.25 * (R1 + R2) / R1
VDD
VDDA
R_2
V_drive is 3.3 V above -VDC
Proximity sensor (APDS 9960) I2C address: 0x39
UART
Both LEVER and I2C_INT can generate a rising edge on WAKEUP pin of STM32 (both signals are active low).
I2C bus is used for proximity sensor and audio amplifier.
HSE is necessary for USB
LSE is necessary for accurate RTC
EEPROM uses a seperate I2C bus
Jumpers select between SDIO and SPI signals for SD card 1) SDIO - 2) SPI
SD card can be powered down with this low side switch
Option to permanently enable DCDC (for testing without STM32)
Filament voltage
Additional circuitry for STM32
Audio amplifier I2C address: 0x34
Audio output can be directly wired to the speaker if wires are shorter than 100 mm.

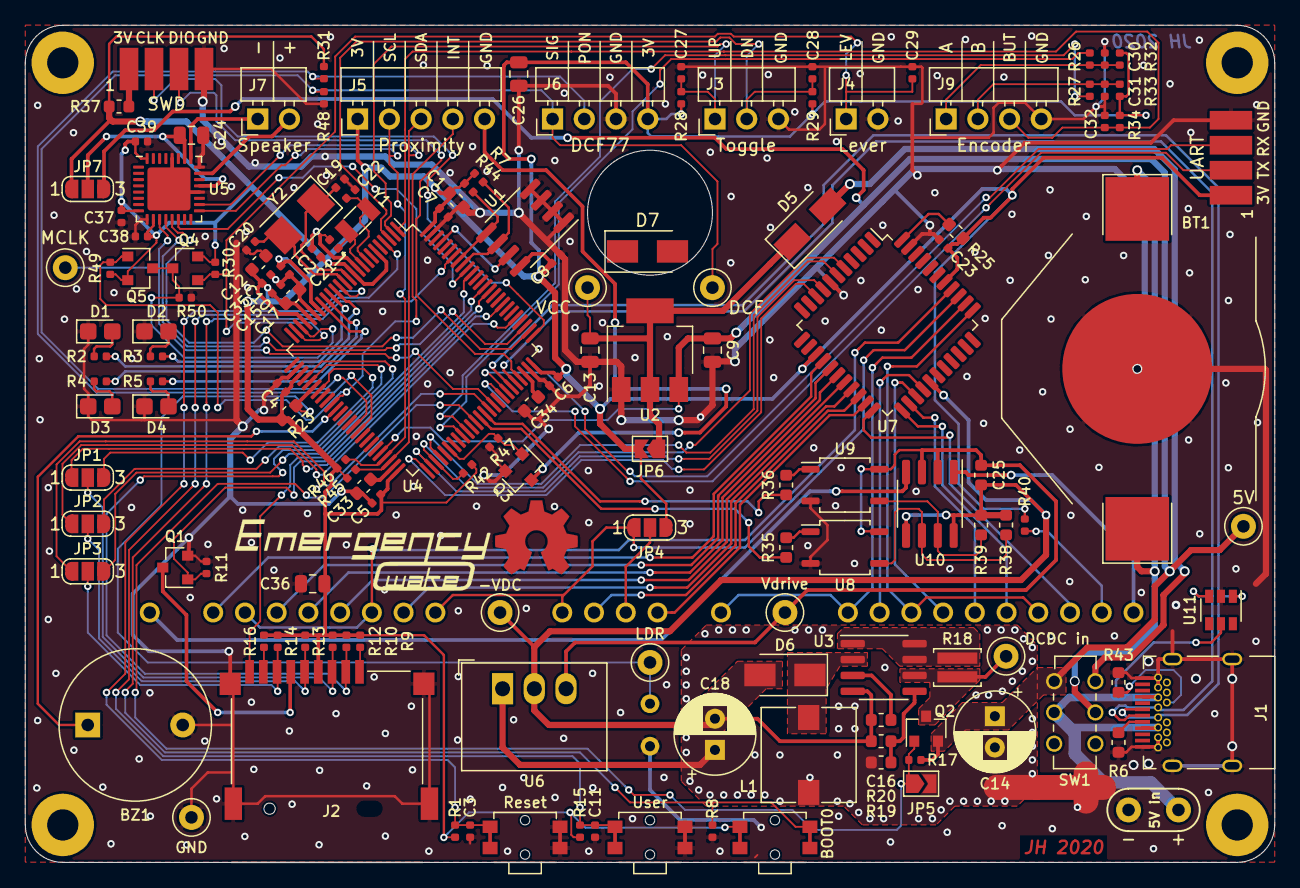
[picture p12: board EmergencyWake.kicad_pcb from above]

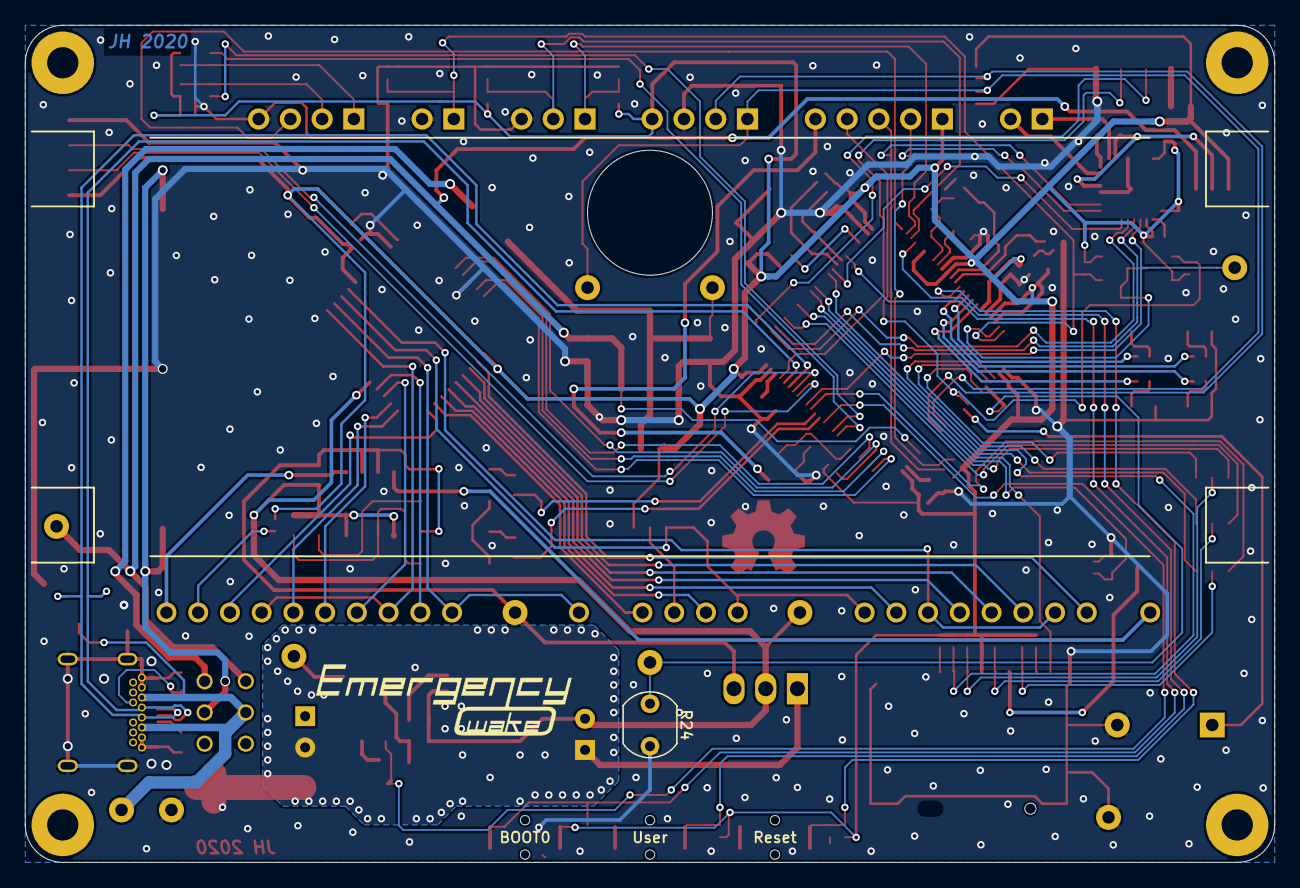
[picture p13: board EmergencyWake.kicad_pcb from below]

Board: 2 copper layers, 100.0 x 67.0 mm, 148 parts (2 on the bottom side), 117 nets.

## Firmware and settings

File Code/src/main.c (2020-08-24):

#include <string.h>

#include "ch.h"
#include "hal.h"

#include "chprintf.h"
#include "shell.h"

#include "ew_devicestatus.h"
#include "ew_audio.h"
#include "ew_display.h"
#include "ew_events.h"
#include "ew_shell.h"
#include "ew_statemachine.h"
#include "ew_time.h"

//===========================================================================
// Variables and local functions
//===========================================================================

// Event listener for main thread statemachine.
event_source_t statemachine_event;
event_listener_t el_statemachine;

// Short startup beep
static void startupBuzzer(void) {
    palSetLine(LINE_BUZZER);
    chThdSleepMilliseconds(100);
    palClearLine(LINE_BUZZER);
    chThdSleepMilliseconds(50);
    palSetLine(LINE_BUZZER);
    chThdSleepMilliseconds(100);
    palClearLine(LINE_BUZZER);
}

//===========================================================================
// Threads and working areas
//===========================================================================

THD_WORKING_AREA(audio_wa, 1024);
THD_WORKING_AREA(display_wa, 128);
static THD_WORKING_AREA(blinker_wa, 128);

static THD_FUNCTION(blinkerThd, arg) {
    (void)arg;
    chRegSetThreadName("blinker");
    while (true) {
        palSetLine(LINE_LED1);
        chThdSleepMilliseconds(100);
        palSetLine(LINE_LED2);
        chThdSleepMilliseconds(500);
        palClearLine(LINE_LED1);
        chThdSleepMilliseconds(100);
        palClearLine(LINE_LED2);
        chThdSleepMilliseconds(500);
    }
}

//===========================================================================
// Command line configuration
//===========================================================================

#define SHELL_WA_SIZE THD_WORKING_AREA_SIZE(2048)
static const ShellCommand commands[] = {
    {"tree", cmd_tree},
    {"create", cmd_create},
    {"sdc", cmd_sdc},
    {"i2c", cmd_i2c},
    {NULL, NULL}
};

//===========================================================================
// Global driver configuration (drivers that are used in multiple threads
//===========================================================================

static const I2CConfig i2ccfg = {
    OPMODE_I2C,
    100000,
    STD_DUTY_CYCLE,
};

//static uint8_t sd_scratchpad[512];    // Working area for SDC driver (still necessary?)
static const SDCConfig sdccfg = {
    SDC_MODE_1BIT
};

static const ShellConfig shell_cfg = {
    (BaseSequentialStream *)&SD1,
    commands
};

//===========================================================================
// Events and callbacks
// check ew_events.h for further explanation of how events are used in this project.
// Debouncing all these external interrupts should be done by hardware (low pass filter on every input).
//===========================================================================

static void toggle_cb(void *arg) {
    (void)arg;
    chSysLockFromISR();
    chEvtBroadcastFlagsI(&statemachine_event, EVENT_MASK(EW_TOGGLE_CHANGE));
    chSysUnlockFromISR();
}

static void lever_cb(void *arg) {
    (void)arg;
    chSysLockFromISR();
    // Lever event has two seperate events for falling / rising edge. This could technically be handled by two seperate callback functions.
    if (palReadLine(LINE_LEVER) == LEVER_DOWN)
        chEvtBroadcastFlagsI(&statemachine_event, EVENT_MASK(EW_LEVER_DOWN));
    else
        chEvtBroadcastFlagsI(&statemachine_event, EVENT_MASK(EW_LEVER_UP));
    chSysUnlockFromISR();
}

static void encoder_button_cb(void *arg) {
    (void)arg;
    chSysLockFromISR();
    chEvtBroadcastFlagsI(&statemachine_event, EVENT_MASK(EW_ENCODER_BUTTON));
    chSysUnlockFromISR();
}

// currently the proximity sensor interrupt is only used to wakeup device from standby and not during operation
/*
static void proximity_interrupt_cb(void *arg) {
    (void)arg;
    chSysLockFromISR();
    chEvtBroadcastFlagsI(&statemachine_event, EVENT_MASK(EW_LEVER_UP));
    chSysUnlockFromISR();
}
*/

static void rtc_alarm_cb(void *arg) {
    (void)arg;
    chSysLockFromISR();
    // if RTC alarm A (minute interrupt)
    chEvtBroadcastFlagsI(&display_event, EVENT_MASK(EW_DISPLAY_REFRESH));       // signal minute interrupt to display thread
    // else (user alarm)
    chEvtBroadcastFlagsI(&statemachine_event, EVENT_MASK(EW_USER_ALARM));
    chSysUnlockFromISR();
}


// For TIM 4, used to read rotary encoder, no ChibiOS HAL is used 
CH_IRQ_HANDLER(STM32_TIM4_HANDLER) {
    CH_IRQ_PROLOGUE();

    chSysLockFromISR();
    STM32_TIM4->SR = 0;  // clear all pending TIM4 interrupts
    // encoder changed event has an additional flag, indicating the direction (flag set for positive direction)
    if (STM32_TIM4->CR1 & TIM_CR1_DIR)
        chEvtBroadcastFlagsI(&statemachine_event, EVENT_MASK(EVENT_FLAGS_OFFSET + EW_ENCODER_CHANGED) | EVENT_MASK(EW_ENCODER_CHANGED));
    else
        chEvtBroadcastFlagsI(&statemachine_event, EVENT_MASK(EW_ENCODER_CHANGED));
    chSysUnlockFromISR();

    CH_IRQ_EPILOGUE();
}

//===========================================================================
// Application entry point
//===========================================================================

int main(void) {    
    // System initialization
    halInit();
    chSysInit();
    startupBuzzer();

    bool restart_after_standby = PWR->CSR & PWR_CSR_SBF;     // did the device just wake up from standby?
    PWR->CR |= PWR_CR_CSBF;                                     // clear standby flag

    // init event source for statemachine
    chEvtObjectInit(&statemachine_event);

    // register this event source as event 0 at our listener
    chEvtRegister(&statemachine_event, &el_statemachine, 0);

    // retrieve device status from eeprom and RTC backup registers
    retrieveDeviceStatus();

    // initialize RTC unit and assign callback functions (next alarm and minute wakeup)

    // start all peripheral drivers that are used in multiple threads (project wide)
    i2cStart(&I2CD2, &i2ccfg);
    sdcStart(&SDCD1, &sdccfg);
    sdStart(&SD1, NULL);

    // start threads
    chThdCreateStatic(blinker_wa, sizeof(blinker_wa), NORMALPRIO - 1, blinkerThd, NULL);
    chThdCreateStatic(audio_wa, sizeof(audio_wa), NORMALPRIO + 1, audioThd, NULL);
    chThdCreateStatic(display_wa, sizeof(display_wa), NORMALPRIO, displayThd, NULL);
    
    thread_t *shelltp = chThdCreateFromHeap(NULL, SHELL_WA_SIZE, "shell", NORMALPRIO, shellThread, (void *)&shell_cfg);

    // initialize timer for rotary encoder and assign callback function
    rccEnableTIM4(true);
    STM32_TIM4->SMCR = 3;           // encoder mode 3
    STM32_TIM4->CCER = 0;           // rising edge polarity
    STM32_TIM4->ARR = 0x1;          // count between 0 and 1 -> update interrupt occurs every two pulses, matches encoder datasheet
    STM32_TIM4->CCMR1 = 0xc1c1;     // f_DTS/16, N = 8 IC1->TI1, IC2->TI2
    STM32_TIM4->CNT = 0;             // initialize counter
    //STM32_TIM4->EGR = 1;           // generate an update event, clearing the counter
    STM32_TIM4->CR1 = 1;                     // enable the counter
    STM32_TIM4->SR = 0;                      // clear all pending interrupts
    STM32_TIM4->DIER = 1;                    // enable update interrupt
    nvicEnableVector(STM32_TIM4_NUMBER, 7);  // enable TIM4 interrupt vector with priority 7 (default priority from mcuconf.h)

    // activate external interrupts for lever, toggle and buttons and assign callback functions
    palEnableLineEvent(LINE_TOGGLE_UP, PAL_EVENT_MODE_BOTH_EDGES);
    palEnableLineEvent(LINE_TOGGLE_DN, PAL_EVENT_MODE_BOTH_EDGES);
    palSetLineCallback(LINE_TOGGLE_UP, toggle_cb, NULL);
    palSetLineCallback(LINE_TOGGLE_DN, toggle_cb, NULL);

    palEnableLineEvent(LINE_LEVER, PAL_EVENT_MODE_BOTH_EDGES);
    palSetLineCallback(LINE_LEVER, lever_cb, NULL);

    palEnableLineEvent(LINE_ENC_BUT, PAL_EVENT_MODE_FALLING_EDGE);
    palSetLineCallback(LINE_ENC_BUT, encoder_button_cb, NULL);

    /*
    palEnableLineEvent(LINE_I2C_INT, PAL_EVENT_MODE_FALLING_EDGE);
    palSetLineCallback(LINE_I2C_INT, proximity_interrupt_cb, NULL);
    */

    // if woken up from standby, this might be because of a user alarm. if this is the case, immediately enter alarm ringing state
    if (restart_after_standby) {
        /*
        uint16_t alarm_flags = (RTC->ISR & (RTC_ISR_ALRAF | RTC_ISR_ALRBF)) >> RTC_ISR_ALRAF_Pos;
        if (alarm_flags > 0) current_state = 
        device_status.state = enterAlarmRinging();
        */
    }
    // if not restarting from standby, power was gone so RTC unit needs to be re-initialized
    else {
        ew_time_t temp = {0, 0};
        initRTC(temp);
        device_status.state = enterIdle(EW_TIMEOUT_LONG);
    }

    // wait for an event to occur
    while (true) {
        eventmask_t new_event = chEvtWaitAny(0);
        // retrieve event flags - check ew_event.h for more information on how events and event flags are used in this project.
        eventflags_t flags = chEvtGetAndClearFlags(&el_statemachine);
        handleEvent((uint16_t)(flags & 0xffff), (uint16_t)((flags >> EVENT_FLAGS_OFFSET) & 0xffff));
    }    

}  // end of main()

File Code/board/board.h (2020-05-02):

/*
    ChibiOS - Copyright (C) 2006..2018 Giovanni Di Sirio

    Licensed under the Apache License, Version 2.0 (the "License");
    you may not use this file except in compliance with the License.
    You may obtain a copy of the License at

        http://www.apache.org/licenses/LICENSE-2.0

    Unless required by applicable law or agreed to in writing, software
    distributed under the License is distributed on an "AS IS" BASIS,
    WITHOUT WARRANTIES OR CONDITIONS OF ANY KIND, either express or implied.
    See the License for the specific language governing permissions and
    limitations under the License.
*/

/*
 * This file has been automatically generated using ChibiStudio board
 * generator plugin. Do not edit manually.
 */

#ifndef BOARD_H
#define BOARD_H

/*===========================================================================*/
/* Driver constants.                                                         */
/*===========================================================================*/

/*
 * Setup for STMicroelectronics STM32F4-Discovery board.
 */

/*
 * Board identifier.
 */
#define BOARD_EMERGENCY_WAKE
#define BOARD_NAME                  "Emergency Wake"

/*
 * Board oscillators-related settings.
 */
#if !defined(STM32_LSECLK)
#define STM32_LSECLK                32768U
#endif

#if !defined(STM32_HSECLK)
#define STM32_HSECLK                8000000U
#endif

/*
 * Board voltages.
 * Required for performance limits calculation.
 */
#define STM32_VDD                   330U

/*
 * MCU type as defined in the ST header.
 */
#define STM32F407xx

/*
 * IO pins assignments.
 */
#define GPIOA_WAKEUP                0U
#define GPIOA_LEVER                 1U
#define GPIOA_PIN2                  2U
#define GPIOA_PIN3                  3U
#define GPIOA_SD_CS                 4U
#define GPIOA_SD_SCK                5U
#define GPIOA_LDR                   6U
#define GPIOA_SD_MOSI               7U
#define GPIOA_PIN8                  8U
#define GPIOA_UART_TX               9U
#define GPIOA_UART_RX               10U
#define GPIOA_USB_DM                11U
#define GPIOA_USB_DP                12U
#define GPIOA_SWDIO                 13U
#define GPIOA_SWCLK                 14U
#define GPIOA_I2S_WS                15U

#define GPIOB_I2C_INT               0U
#define GPIOB_BUZZER                1U
#define GPIOB_PIN2                  2U
#define GPIOB_PIN3                  3U
#define GPIOB_SD_MISO               4U
#define GPIOB_I2S_SD                5U
#define GPIOB_EEPROM_SCL            6U
#define GPIOB_EEPROM_SDA            7U
#define GPIOB_PIN8                  8U
#define GPIOB_PIN9                  9U
#define GPIOB_I2C_SCL               10U
#define GPIOB_I2C_SDA               11U
#define GPIOB_SPI_STB               12U
#define GPIOB_SPI_SCK               13U
#define GPIOB_SPI_MISO              14U
#define GPIOB_SPI_MOSI              15U

#define GPIOC_LED1                  0U
#define GPIOC_LED2                  1U
#define GPIOC_LED3                  2U
#define GPIOC_LED4                  3U
#define GPIOC_PIN4                  4U
#define GPIOC_PIN5                  5U
#define GPIOC_FILA                  6U
#define GPIOC_FILB                  7U
#define GPIOC_SD_D0                 8U
#define GPIOC_I2S_MCLK              9U
#define GPIOC_I2S_CK                10U
#define GPIOC_PIN11                 11U
#define GPIOC_SD_CK                 12U
#define GPIOC_PIN13                 13U
#define GPIOC_OSC32 IN              14U
#define GPIOC_OSC32_OUT             15U

#define GPIOD_PIN0                  0U
#define GPIOD_PIN1                  1U
#define GPIOD_SD_CMD                2U
#define GPIOD_PIN3                  3U
#define GPIOD_PIN4                  4U
#define GPIOD_SD_EN                 5U
#define GPIOD_SD_DET                6U
#define GPIOD_PIN7                  7U
#define GPIOD_PIN8                  8U
#define GPIOD_PROX_EN               9U
#define GPIOD_PIN10                 10U
#define GPIOD_PIN11                 11U
#define GPIOD_ENC_A                 12U
#define GPIOD_ENC_B                 13U
#define GPIOD_PIN14                 14U
#define GPIOD_DCDC_EN               15U

#define GPIOE_EEPROM_NWC            0U
#define GPIOE_PIN1                  1U
#define GPIOE_ENC_BUT               2U
#define GPIOE_TOGGLE_UP             3U
#define GPIOE_TOGGLE_DN             4U
#define GPIOE_USER_BUT              5U
#define GPIOE_PIN6                  6U
#define GPIOE_PIN7                  7U
#define GPIOE_PIN8                  8U
#define GPIOE_DCF_SIG               9U
#define GPIOE_DCF_EN                10U
#define GPIOE_PIN11                 11U
#define GPIOE_PIN12                 12U
#define GPIOE_PIN13                 13U
#define GPIOE_PIN14                 14U
#define GPIOE_5V_SENSE              15U

/*
 * EmergencyWake board assignments.
 */
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

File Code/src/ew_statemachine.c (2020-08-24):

//===========================================================================
// Functions for handling the main statemachine.
// Involves reacting to different events and switching between states
//===========================================================================

#include "ch.h"
#include "hal.h"

#include <string.h>
#include "chprintf.h"

#include "ew_statemachine.h"
#include "ew_events.h"
#include "ew_time.h"
#include "ew_devicestatus.h"
#include "ew_eeprom.h"

//===========================================================================
// Variables and local functions
//===========================================================================

// used to store systime when lever gets pulled down
static systime_t lever_down_time;

//===========================================================================
// functions for entering a new state
//===========================================================================

ew_state_t enterIdle(int display_timeout) {
    // tell display thread to show current time and activated alarms, enable second blink
    // start standby timer depending on value of display_timeout
    return EW_IDLE;
}

static ew_state_t enterShowAlarm(void) {
    // tell display thread to show alarm a or b, no second blink, highlight selected alarm number
    return EW_SHOW_ALARM;
}

static ew_state_t enterSetHours(void) {
    // tell display thread to only display hours of current time or selected alarm (maybe display minutes in lower brightness)
    return EW_SET_HOURS;
}

static ew_state_t enterSetMinutes(void) {
    // tell display thread to only display minutes of current time or selected alarm
    return EW_SET_MINUTES;
}

ew_state_t enterAlarmRinging(void) {
    // tell audio thread to start playing alarm sound
    device_status.active_alarm = device_status.next_alarm;
    chEvtBroadcastFlags(&audio_event, EVENT_MASK(EW_AUDIO_PLAY_ALARM));
    // TODO: start timeout timer to stop alarm after x minutes if no one pays attention
    return EW_ALARM_RINGING;
}

static ew_state_t enterStandby(void) {
    // tell display thread to shut down DCDC converter and display driver IC
    chEvtBroadcastFlags(&display_event, EVENT_MASK(EW_DISPLAY_TURNOFF));
    // wait for display thread to terminate

    // tell audio thread to stop playing any sound and disable the audio codec IC and MCLK
    chEvtBroadcastFlags(&audio_event, EVENT_MASK(EW_AUDIO_TURNOFF));
    // wait for audio thread to terminate

    // save current configuration to eeprom
    saveToEeprom();

    PWR->CSR |= (PWR_CSR_EWUP);                    // enable wakeup on pin PA0
    RTC->ISR &= ~(RTC_ISR_ALRBF | RTC_ISR_ALRAF);  // clear RTC alarm flags
    // disable RTC alarm A (minute interrupt)
    PWR->CR |= (PWR_CR_CSBF | PWR_CR_CWUF);  // clear wakeup flag -> any wakeup event after this instruction will keep device from entering standby

    // tell proximity thread to clear interrupt from proximity sensor and disable ambient light engine

    // go into standby
    chSysLock();
    SCB->SCR |= SCB_SCR_SLEEPDEEP_Msk;
    PWR->CR |= (PWR_CR_PDDS);               // enable standby instead of stop mode when entering deepsleep
    //__WFI();

    return EW_STANDBY;
}

//===========================================================================
// main state machine handler
//===========================================================================

void handleEvent(uint16_t new_event, uint16_t flags) {
    ew_state_t old_state = device_status.state;
    ew_state_t new_state = old_state;

    // as long as the lever is held down (and hasn't just been pulled down), don't process any new events
    if (palReadLine(LINE_LEVER) == LEVER_DOWN && !(new_event & EVENT_MASK(EW_LEVER_DOWN))) return;

    // get current state of toggle.
    // It determines which screen is displayed and what value all user actions like changing hours or minutes apply to (system time or user alarm one or two)
    updateToggleState();

    chprintf((BaseSequentialStream*)&SD1, "Handling event: 0x%x - ", new_event);

    // Check each event. It is possible to handle multiple events in the same cycle.
    // The order of checks should make sure they still yield the correct result.
    // Most checks keep the device in the same state. If not, this is indicated by assigning a new value to the variable new_state.

    if (new_event & EVENT_MASK(EW_USER_ALARM)) {
        // user alarm
        chprintf((BaseSequentialStream*)&SD1, "User alarm\n");
        new_state = enterAlarmRinging();
    }

    if (new_event & EVENT_MASK(EW_LEVER_DOWN)) {
        // lever pulled down
        chprintf((BaseSequentialStream*)&SD1, "Lever pulled down\n");

        switch (old_state) {
            case EW_ALARM_RINGING:
                chEvtBroadcastFlags(&audio_event, EVENT_MASK(EW_AUDIO_STOP_ALARM));       // stop alarm sound and remember at what time the lever was pulled down
                lever_down_time = chVTGetSystemTimeX();
                break;
            case EW_SHOW_ALARM:
                toggleAlarmEnable(device_status.toggle_state);
                break;
            case EW_SET_HOURS:
            case EW_SET_MINUTES:
                if (device_status.toggle_state == EW_ALARM_NONE) toggleDST();     // toggling DST only available while setting up system time
                break;
            default:
                break;
        }
    }

    if (new_event & EVENT_MASK(EW_LEVER_UP)) {
        // lever released
        chprintf((BaseSequentialStream*)&SD1, "Lever released\n");

        switch (old_state) {
            case EW_IDLE:
                new_state = enterStandby();
                break;
            case EW_ALARM_RINGING:
                // if lever is released within 2 seconds after pulling down -> enable snooze, if not -> restore saved alarm
                if (chVTIsSystemTimeWithinX(lever_down_time, lever_down_time + TIME_MS2I(2000))) {
                    increaseSnoozeTime(device_status.active_alarm);
                    chEvtBroadcastFlags(&audio_event, EVENT_MASK(EW_AUDIO_SNOOZE_ALARM));       // play alarm snoozed sound
                } 
                else {
                    chEvtBroadcastFlags(&audio_event, EVENT_MASK(EW_AUDIO_STOP_ALARM));         // play alarm stopped sound
                }
                device_status.active_alarm = EW_ALARM_NONE;                         // no alarm is ringing anymore
                // recalculate next alarm
                device_status.next_alarm = findNextAlarm();
                device_status.next_alarm_time = findNextAlarmTime();
                if (device_status.toggle_state == EW_ALARM_NONE) new_state = enterIdle(EW_TIMEOUT_SHORT);
                else new_state = enterShowAlarm();
                break;
            default:
                break;
        }
    }

    if (new_event & EVENT_MASK(EW_TOGGLE_CHANGE)) {
        // toggle changed
        chprintf((BaseSequentialStream*)&SD1, "Toggle changed\n");
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

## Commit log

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2020-01-20 [Readme] New toggle switch, link to encoder, typos
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2020-01-23 [Board] Started layout with mechanically fixed components
    [EmergencyWake.kicad_pcb, EmergencyWake.sch]
2020-01-23 [Board] Added a lot of main components
    [EmergencyWake.kicad_pcb, EmergencyWake.sch]
2020-01-24 [Board] Added a lot more components to schematic
    [EmergencyWake.sch]
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2020-01-25 [Board] Added IC and wiring for VFD
    [EmergencyWake.sch]
2020-01-25 [Board] Added motor driver for VFD filament
    [EmergencyWake.sch]
2020-01-27 [Board] Added all remaining components, arranged them approximately on PCB
    [EmergencyWake.kicad_pcb, EmergencyWake.sch]
2020-01-29 [Board] Switched some pins in CubeMX
    [EmergencyWake.sch]
2020-01-31 [Board] Changed VFD driver, added DC/DC converter for -24V
    [EmergencyWake.sch]
2020-02-01 [Board] Some tweaks on the schematic
    [EmergencyWake.sch]
2020-02-01 [Board] Wired all signals to STM32
    [EmergencyWake.sch, EmergencyWake_Pinout.ods]
2020-02-01 [Board] Cleaned up schematic sections
    [EmergencyWake.sch]
2020-02-02 [Board] Switched some pins around
    [EmergencyWake.sch, EmergencyWake_Pinout.ods]
2020-02-02 [Board] Placed a lot of components!
    [EmergencyWake.kicad_pcb, EmergencyWake.sch]
2020-02-03 [Board] Placed most components, only TPs missing
    [EmergencyWake.kicad_pcb, EmergencyWake.sch]
2020-02-05 [Board] Changed lever to active high, replaced LDO for filament
    [EmergencyWake.kicad_pcb, EmergencyWake.sch]
2020-02-05 [Board] Moved all components to the front of the board
    [EmergencyWake.kicad_pcb]
2020-02-05 [Board] Finished moving components to front of board
    [EmergencyWake.kicad_pcb, EmergencyWake.sch]
2020-02-06 [Board] Checked schematic for errors
    [EmergencyWake.kicad_pcb, EmergencyWake.sch]
2020-02-09 [Images] Added Emergency Wake Logo
    [EmergencyWake_Logo.dxf]
2020-02-09 [Board] Added logo and changed USB plug type
    [EmergencyWake.kicad_pcb, EmergencyWake.sch]
2020-02-09 [Board] Added GNDD and routed DCDC converter
    [EmergencyWake.kicad_pcb, EmergencyWake.sch]
2020-02-10 [Board] Rearranged DCDC converter
    [EmergencyWake.kicad_pcb]
2020-02-11 [Board] Cleaned up silkscreen
    [EmergencyWake.kicad_pcb, EmergencyWake.sch]
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2020-02-12 [Board] Changed SD and battery holder to Würth components
    [EmergencyWake.kicad_pcb, EmergencyWake.sch]
2020-02-12 [Board] Cleanup before changing MCU once again
    [EmergencyWake.kicad_pcb]
2020-02-12 [Board] Switched from F103 to F407
    [EmergencyWake.kicad_pcb, EmergencyWake.sch]
2020-02-13 [Board] Cleand up silk screen
    [EmergencyWake.kicad_pcb]
2020-02-13 [Board] Did some routing
    [EmergencyWake.kicad_pcb]
2020-02-14 [Board] Removed solder paste for not-fitted components. Added I2C for proximity sensor. Moved SWD and UART connector
    [EmergencyWake.kicad_pcb, EmergencyWake.sch]
2020-02-14 [Board] More routing done
    [EmergencyWake.kicad_pcb]
2020-02-16 [Board] More routing
    [EmergencyWake.kicad_pcb, EmergencyWake.sch]
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2020-02-17 [Board] Routed USB, UART and buttons
    [EmergencyWake.kicad_pcb]
2020-02-19 [Board] Added TVS diodes for USB
    [EmergencyWake.kicad_pcb, EmergencyWake.sch]
2020-02-19 [Board] Routing done, cleanup necessary
    [EmergencyWake.kicad_pcb]
2020-02-19 [Board] Routing cleaned up, GND vias missing
    [EmergencyWake.kicad_pcb, EmergencyWake.sch]
2020-02-20 [Board] Fixed some errors
    [EmergencyWake.kicad_pcb, EmergencyWake.sch]
2020-02-20 [Board] Added stitching vias
    [EmergencyWake.kicad_pcb]
2020-02-20 [Board] Some last changes to the layout
    [EmergencyWake.kicad_pcb, EmergencyWake.sch]
2020-02-20 [Board] Generated bills of material for each vendor
    [EmergencyWake_BOM-LCSC.ods, EmergencyWake_BOM-Other.ods, EmergencyWake_BOM-Total.ods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]
2020-02-20 [Board] Added positions file
    [EmergencyWake-Positions.ods, EmergencyWake-Positions.xls, EmergencyWake_BOM-LCSC.ods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]
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2020-02-21 [Board] First version of Gerber files
    [EmergencyWake-B_Cu.gbr, EmergencyWake-B_Mask.gbr, EmergencyWake-B_Paste.gbr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]
2020-02-22 [Code] Modified example project to use USB serial - not working
    [board.h, halconf.h, main.c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]
2020-02-22 [Code] Narrowed down the USB problem
    [main.c, mcuconf.h]
2020-02-22 [Code] Setting higher system speed solved USB problem
    [EmergencyWake_STM32F407.ioc, mcuconf.h]
2020-02-22 [Code] Fixed USB by correctly initializing pins
    [main.c]
2020-02-24 [Code] Copied SDC test, doesn't work yet
    [halconf.h, main.c, mcuconf.h]
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2020-02-25 [Board] Added OR gate for wakeup signal
    [EmergencyWake.kicad_pcb, EmergencyWake.sch]
2020-03-03 [Board] New fabrication files
    [EmergencyWake-B_Cu.gbl, EmergencyWake-B_Mask.gbs, EmergencyWake-B_Paste.gbp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]
2020-03-04 [Board] Corrected assembly information for JLCPCB
    [EmergencyWake-Positions.ods, EmergencyWake-Positions.xls, EmergencyWake.sch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]
2020-03-06 [Board] Some minor changes
    [EmergencyWake.kicad_pcb, EmergencyWake.sch]
2020-03-07 [Board] Final changes for order
    [EmergencyWake-B_Cu.gbl, EmergencyWake-B_Mask.gbs, EmergencyWake-B_Paste.gbp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]
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2020-03-22 [Board] Replaced audio amplifier
    [EmergencyWake.kicad_pcb, EmergencyWake.sch]
2020-03-23 [Board] Cleaned up GND fill around STM32
    [EmergencyWake.kicad_pcb]
2020-03-23 [Board] Minor tweaks, switched position of 5V input and USB protection diodes
    [EmergencyWake.kicad_pcb]
2020-03-25 [Board] Minor Layout changes
    [EmergencyWake.kicad_pcb, EmergencyWake.sch]
2020-03-25 [Board] New assembly information after changing audio amp
    [EmergencyWake-B_Cu.gbl, EmergencyWake-B_Mask.gbs, EmergencyWake-B_Paste.gbp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]
2020-03-26 [Board] Results of DFM analysis at JLCPCB
    [EmergencyWake-Positions.xls]
2020-04-03 [Board] SDC example finally works, updated clocks in CubeMX project to make ChibiOS happy
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2020-04-23 [Code] Added code for audio output. Does not work yet
    [board.c, ew_audio.c, halconf.h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]
2020-04-24 [Code] Fixed static noise, I2S still in wrong state
    [ew_audio.c, mcuconf.h]
2020-04-24 [Code] Fixed I2S frequencies
    [EmergencyWake_STM32F407.ioc, ew_audio.c, mcuconf.h]
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2020-04-27 [Code] Implemented display driver. Still buggy
    [EmergencyWake_STM32F407.ioc, board.c, board.h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]
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2020-04-29 [Code] Buzzer and encoder work now
    [board.c, board.h, ew_display.c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]
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2020-06-20 [Board] Added diode in front of LDO, exported STEP filefor CAD
    [EmergencyWake.kicad_pcb, EmergencyWake.sch]
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2020-06-21 [CAD] Added construction for Autodesk Inventor 2020
    [1.ipt, 2.ipt, 3.ipt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]
2020-07-02 [CAD] Some changes to the wooden backplate and brass plates
    [EW_Holzplatte.0010.ipt, EW_Holzplatte.0014.ipt, EW_Holzplatte.ipt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]
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2020-08-19 [Code] Reworked statemachine a little bit.
    [ew_statemachine.c, main.c]
2020-08-23 [Code] Major rework of existing code (split into new files).
    [ew_audio.c, ew_display.c]
2020-08-24 [CAD] Increased pre-tension on spring
    [EW_Achsenabschluss.ipt, EmergencyWake.0017.iam, EmergencyWake.iam]
